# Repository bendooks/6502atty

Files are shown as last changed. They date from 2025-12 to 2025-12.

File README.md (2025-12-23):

# 6502 Atty

A 6502 SBC with an ATMega as a contoller and monitor for the 6502.

This is an initial commit as PCBs are off for manufacture and not been tested. This includes the prototype firmware and the first cut of the firmware code.

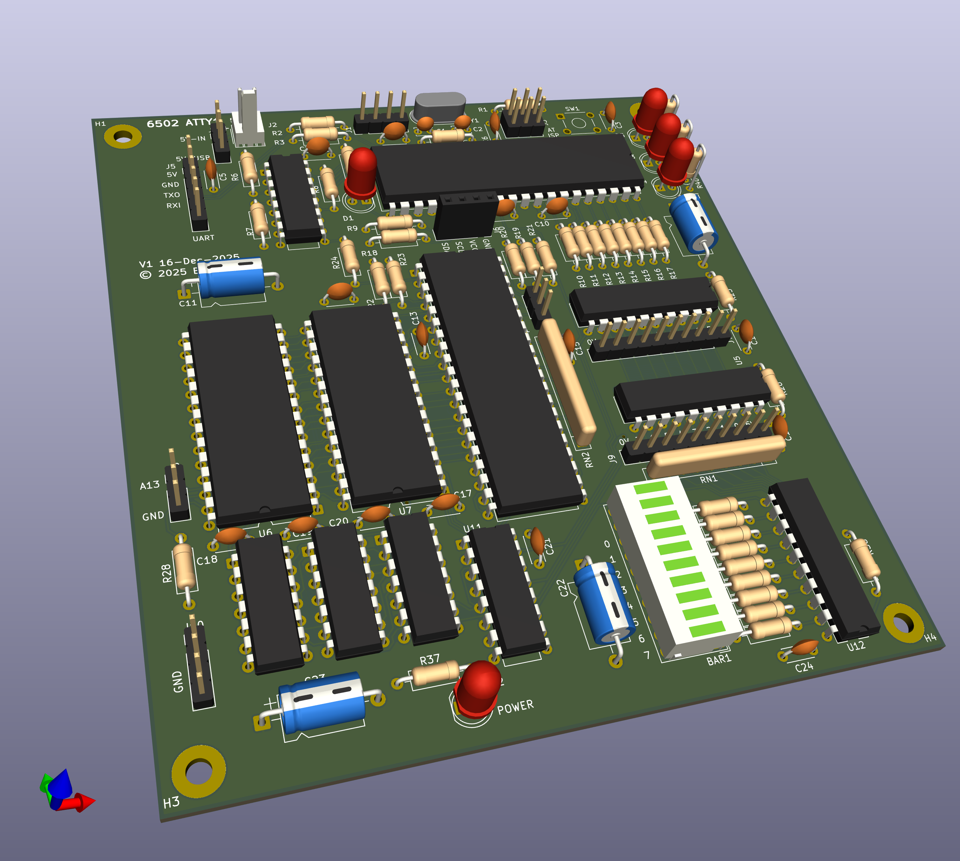
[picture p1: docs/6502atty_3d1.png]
3D PCB view


# Firmware

The firmware is currently in development. To build, you will need at-least avr-gcc and the relevant libraries and is currently only being tested on Linux (Debian). Once built, download to the ATMega using something like avrdude.

## Revision information

The original prototype version was built on a perfboard, and not release.

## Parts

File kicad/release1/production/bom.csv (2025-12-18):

Designator | Footprint | Quantity | Value | LCSC Part #
BAR1 | HDSP-4850 | 1 | HDSP-4850
C1, C2 | C_Disc_D3.4mm_W2.1mm_P2.50mm | 2 | 12pF
C10, C3 | C_Disc_D4.3mm_W1.9mm_P5.00mm | 2 | ~
C11, C22, C23, C8 | CP_Axial_L10.0mm_D6.0mm_P15.00mm_Horizontal | 4 | 100uF/16V
C12, C13, C14, C15, C16, C17, C18, C19, C20, C21, C24, C4, C5, C6, C7, C9 | C_Disc_D4.3mm_W1.9mm_P5.00mm | 16 | 100nF
D1 | LED_D5.0mm | 1 | LED_Small_Filled
D2, D3, D4, D5 | LED_D5.0mm | 4 | RED
J1, J10 | PinHeader_1x04_P2.54mm_Vertical | 2 | Conn_01x04_Pin
J11, J4, J8 | PinHeader_1x03_P2.54mm_Vertical | 3 | Conn_01x03_Pin
J2 | Molex_KK-254_AE-6410-02A_1x02_P2.54mm_Vertical | 1 | Conn_01x02_Pin
J3 | PinHeader_2x03_P2.54mm_Vertical | 1 | Conn_02x03_Odd_Even
J5 | PinHeader_1x06_P2.54mm_Vertical | 1 | Conn_01x06_Pin
J6 | PinSocket_1x04_P2.54mm_Vertical | 1 | Conn_01x04_Pin
J7, J9 | PinHeader_1x10_P2.54mm_Vertical | 2 | Conn_01x10_Pin
R1, R2, R3, R37, R4, R5 | R_Axial_DIN0207_L6.3mm_D2.5mm_P10.16mm_Horizontal | 6 | 1K
R10, R11, R12, R13, R14, R15, R16, R17, R27, R29, R30, R31, R32, R33, R34, R35, R38 | R_Axial_DIN0207_L6.3mm_D2.5mm_P10.16mm_Horizontal | 17 | 330R
R18, R9 | R_Axial_DIN0207_L6.3mm_D2.5mm_P10.16mm_Horizontal | 2 | 4K7
R19, R20, R21, R22, R23, R24, R25, R26, R28, R36, R6, R7, R8 | R_Axial_DIN0207_L6.3mm_D2.5mm_P10.16mm_Horizontal | 13 | R
R39, R40, R41 | R_Axial_DIN0207_L6.3mm_D2.5mm_P2.54mm_Vertical | 3 | 1K
RN1, RN2 | R_Array_SIP9 | 2 | R_Network08
SW1 | SW_TH_Tactile_Omron_B3F-10xx | 1 | SW_Push
U1 | DIP-40_W15.24mm | 1 | ATmega164P-20P
U10 | DIP-14_W7.62mm | 1 | 74LS08
U11 | DIP-16_W7.62mm | 1 | 74LS138
U12, U4 | DIP-20_W7.62mm | 2 | 74LS573
U2 | DIP-16_W7.62mm | 1 | 74LS112
U3 | DIP-40_W15.24mm | 1 | W65C02SxP
U5 | DIP-20_W7.62mm | 1 | 74HC245
U6 | DIP-28_W15.24mm | 1 | 27C128
U7 | DIP-28_W15.24mm | 1 | KM62256CLP
U8, U9 | DIP-14_W7.62mm | 2 | 74LS00
Y1 | Crystal_HC49-4H_Vertical | 1 | 18.341MHz

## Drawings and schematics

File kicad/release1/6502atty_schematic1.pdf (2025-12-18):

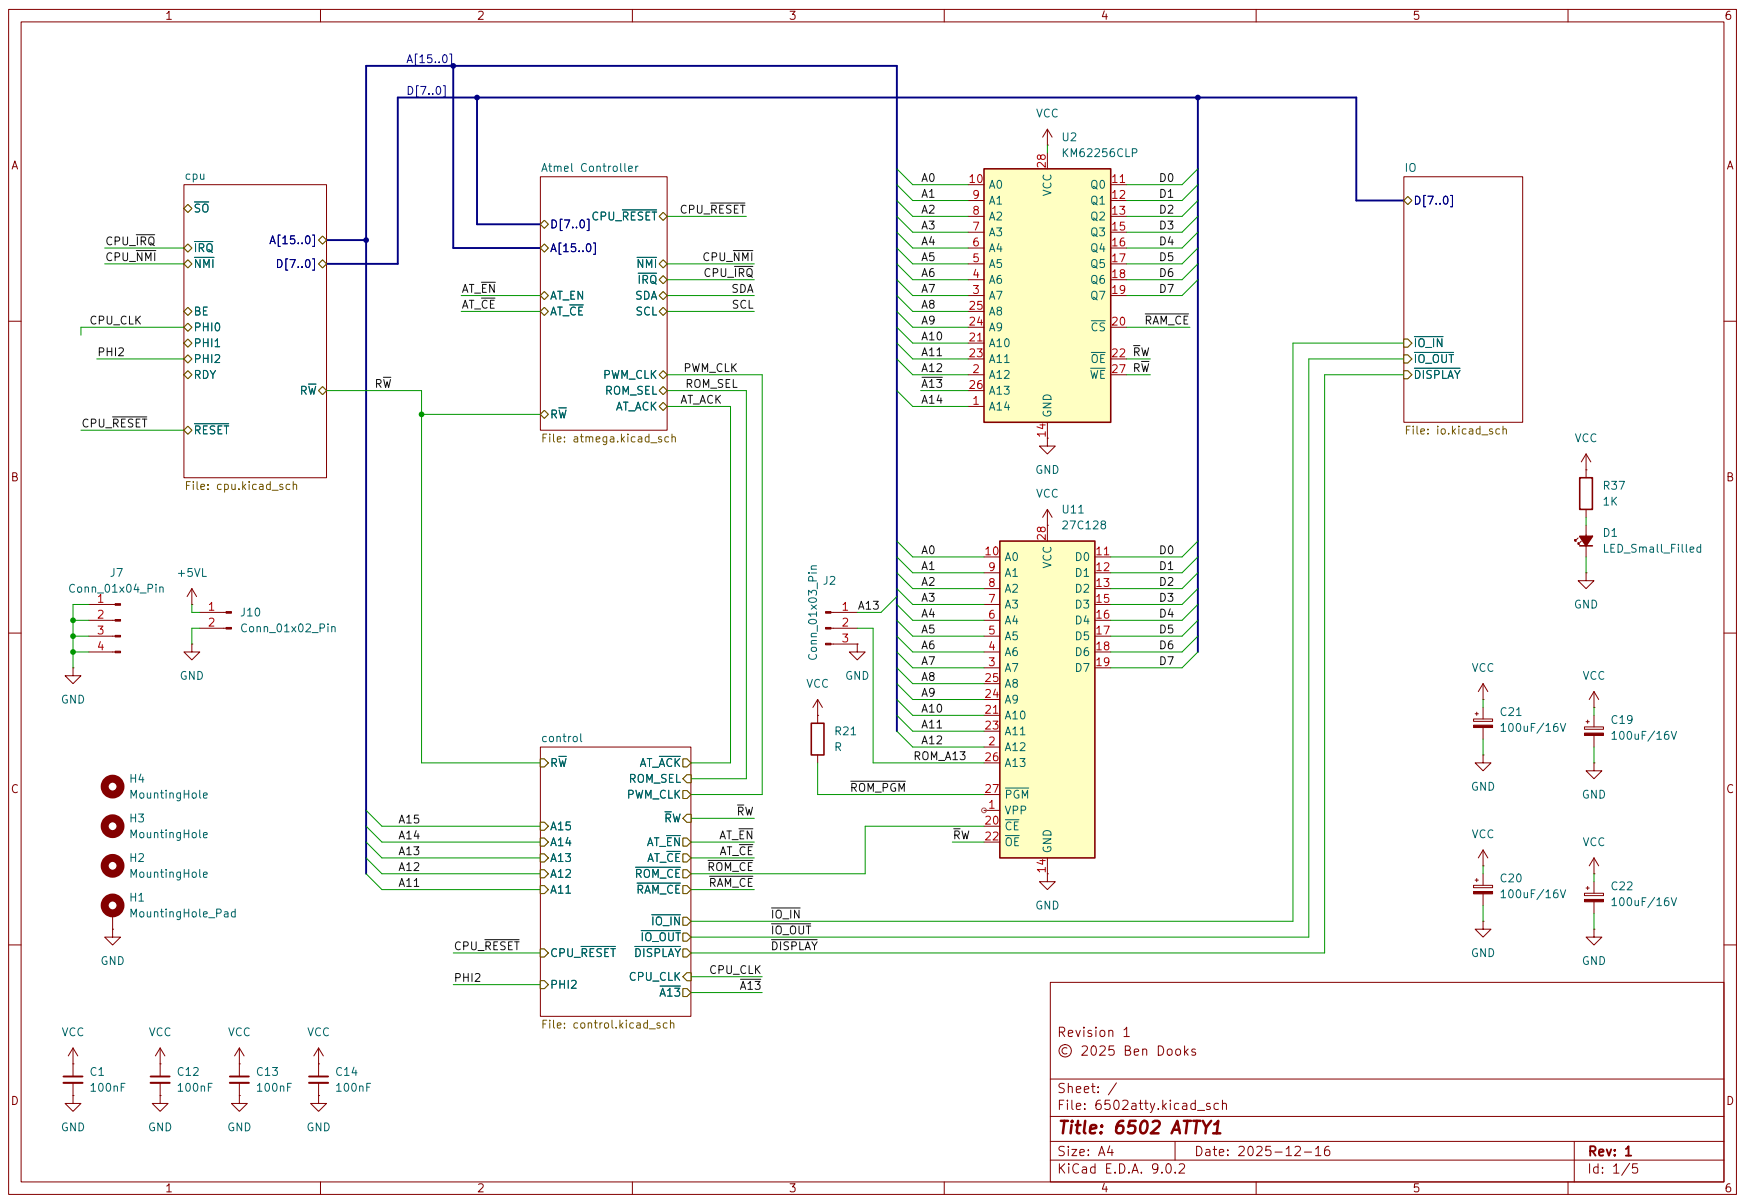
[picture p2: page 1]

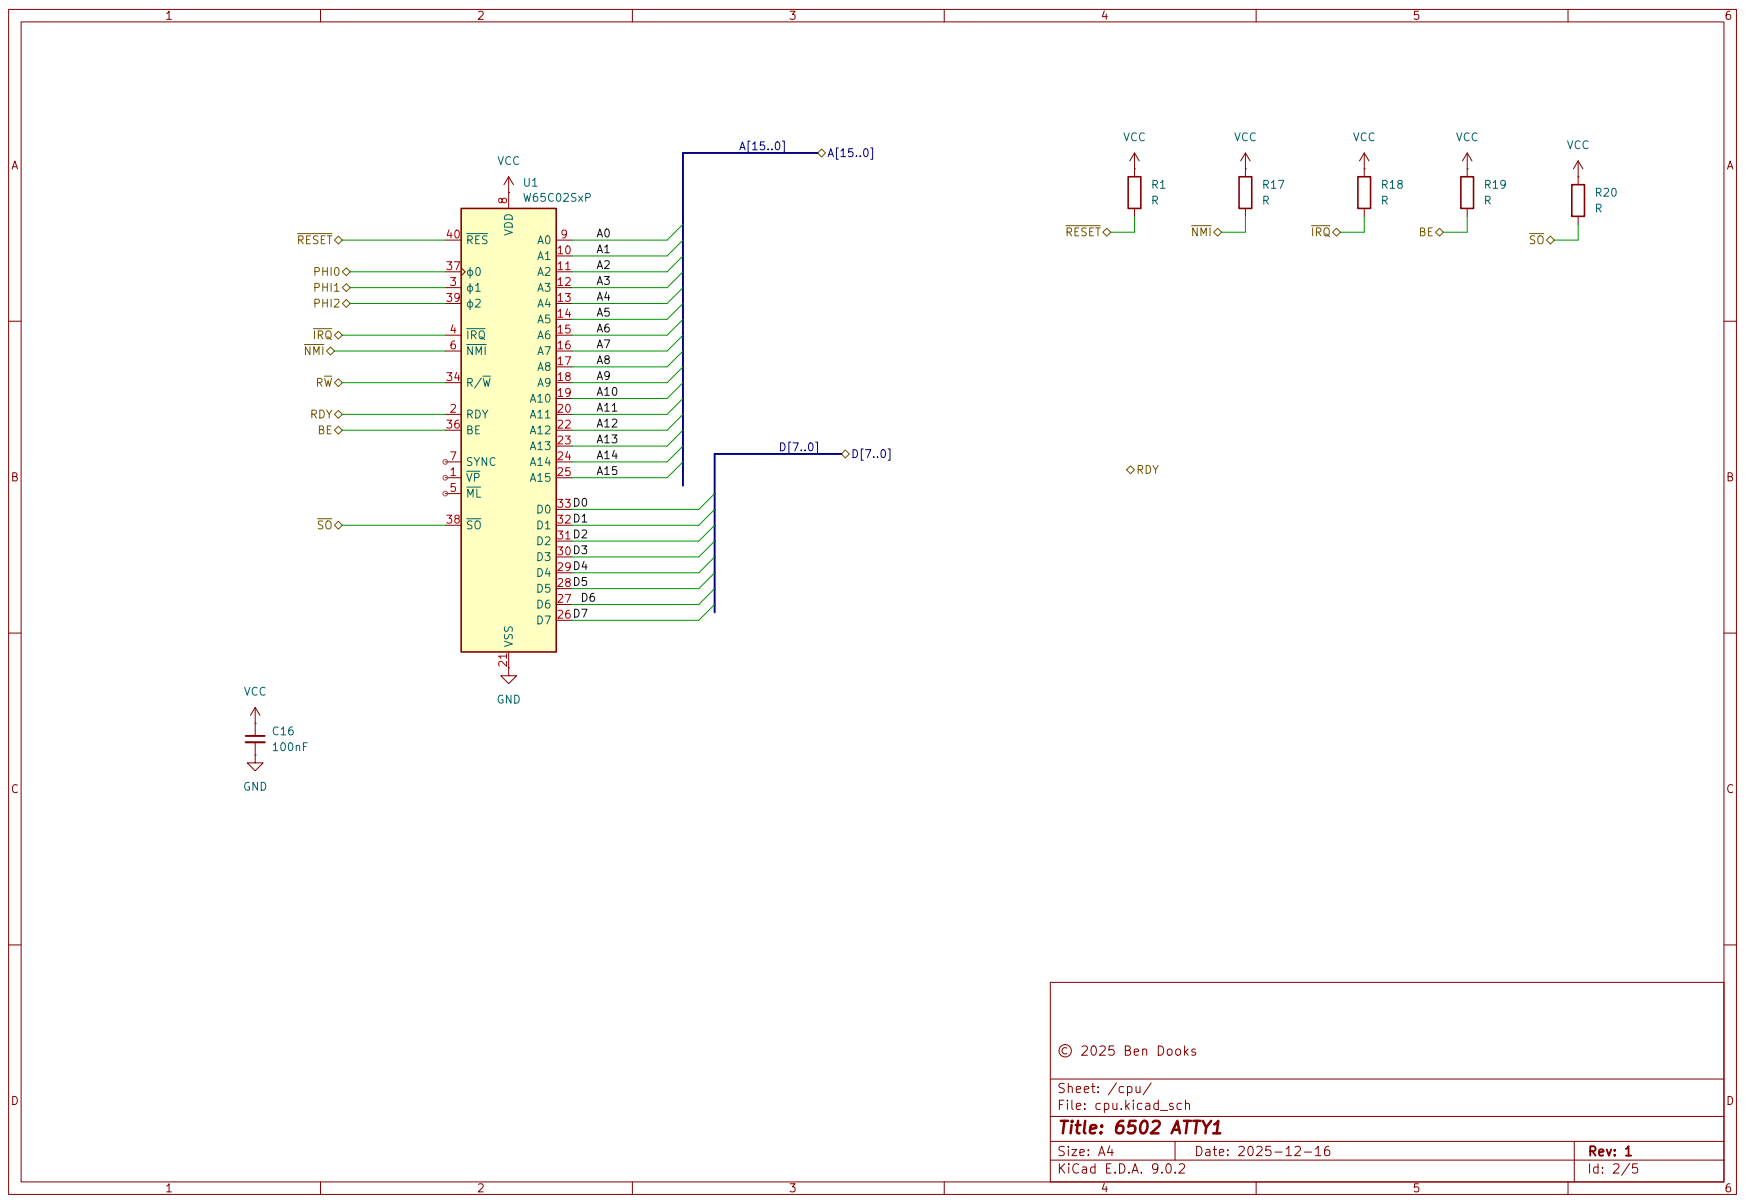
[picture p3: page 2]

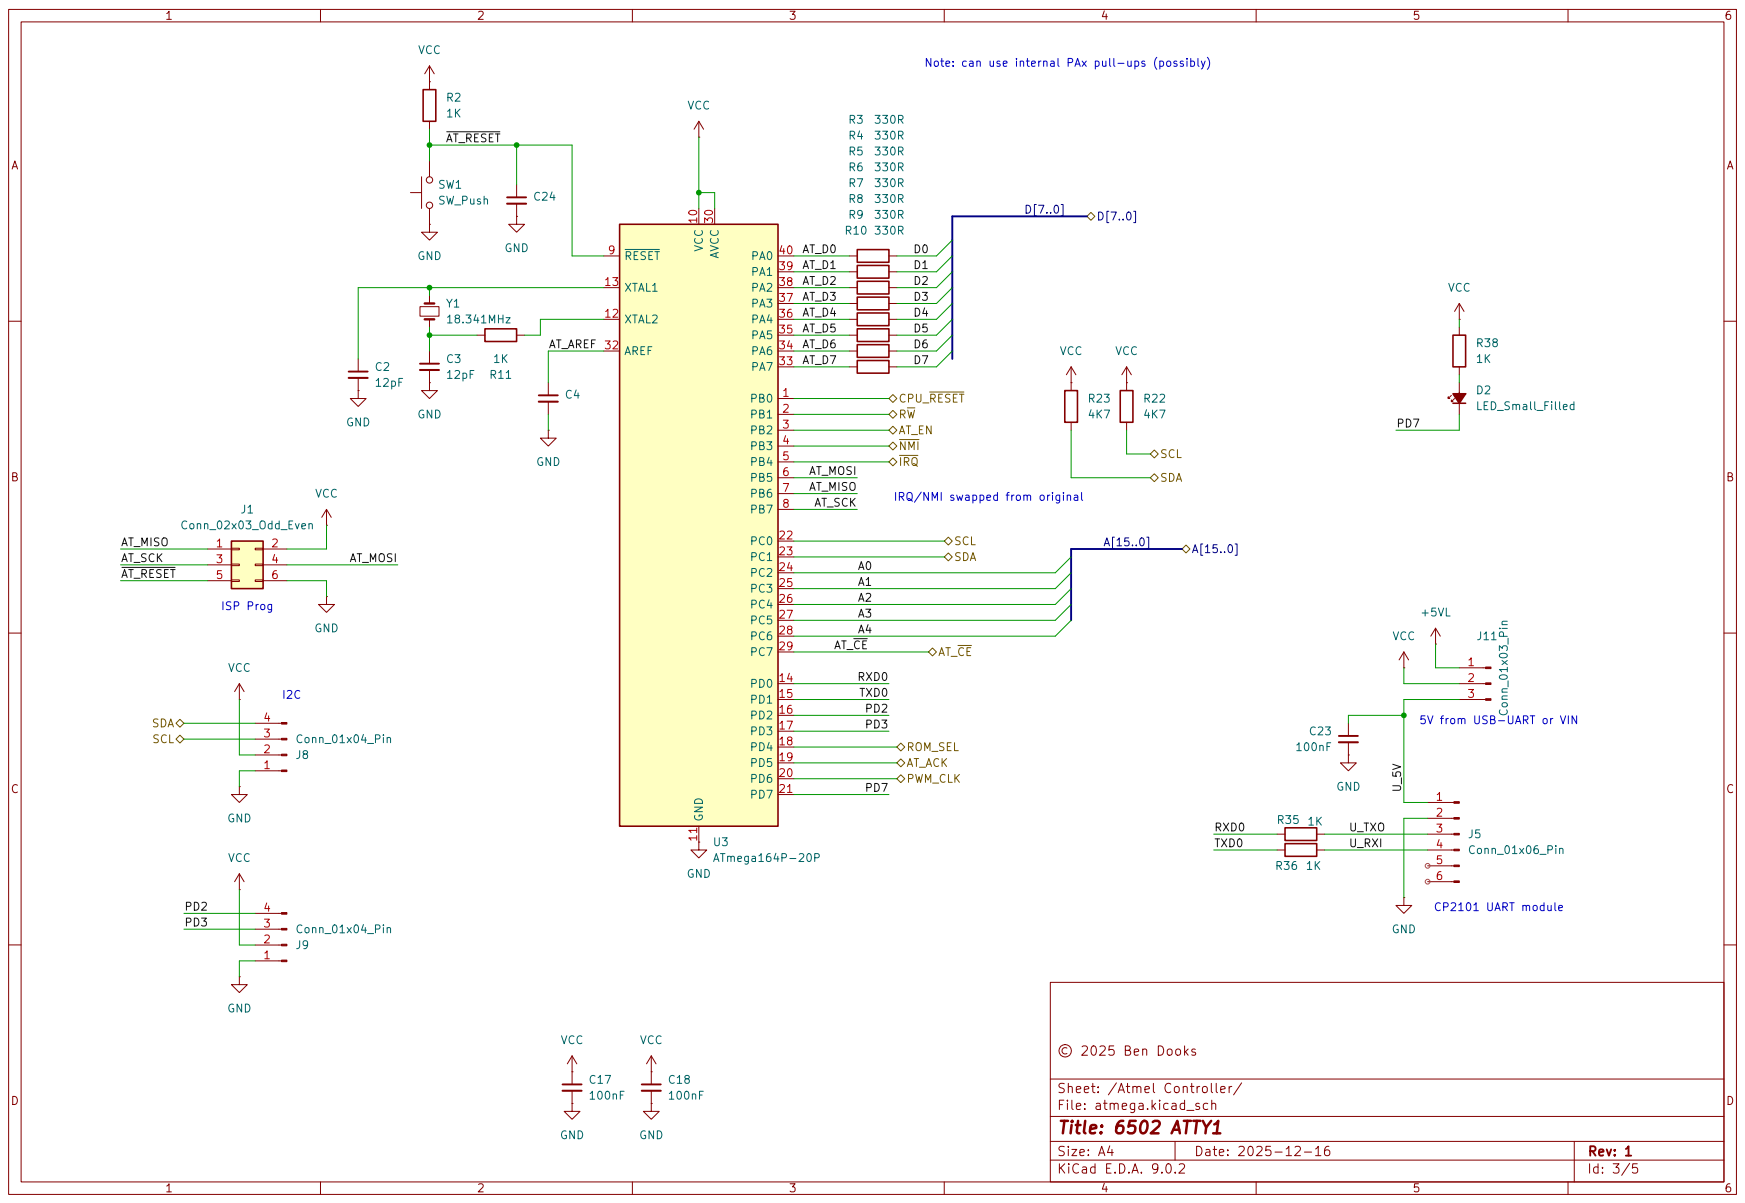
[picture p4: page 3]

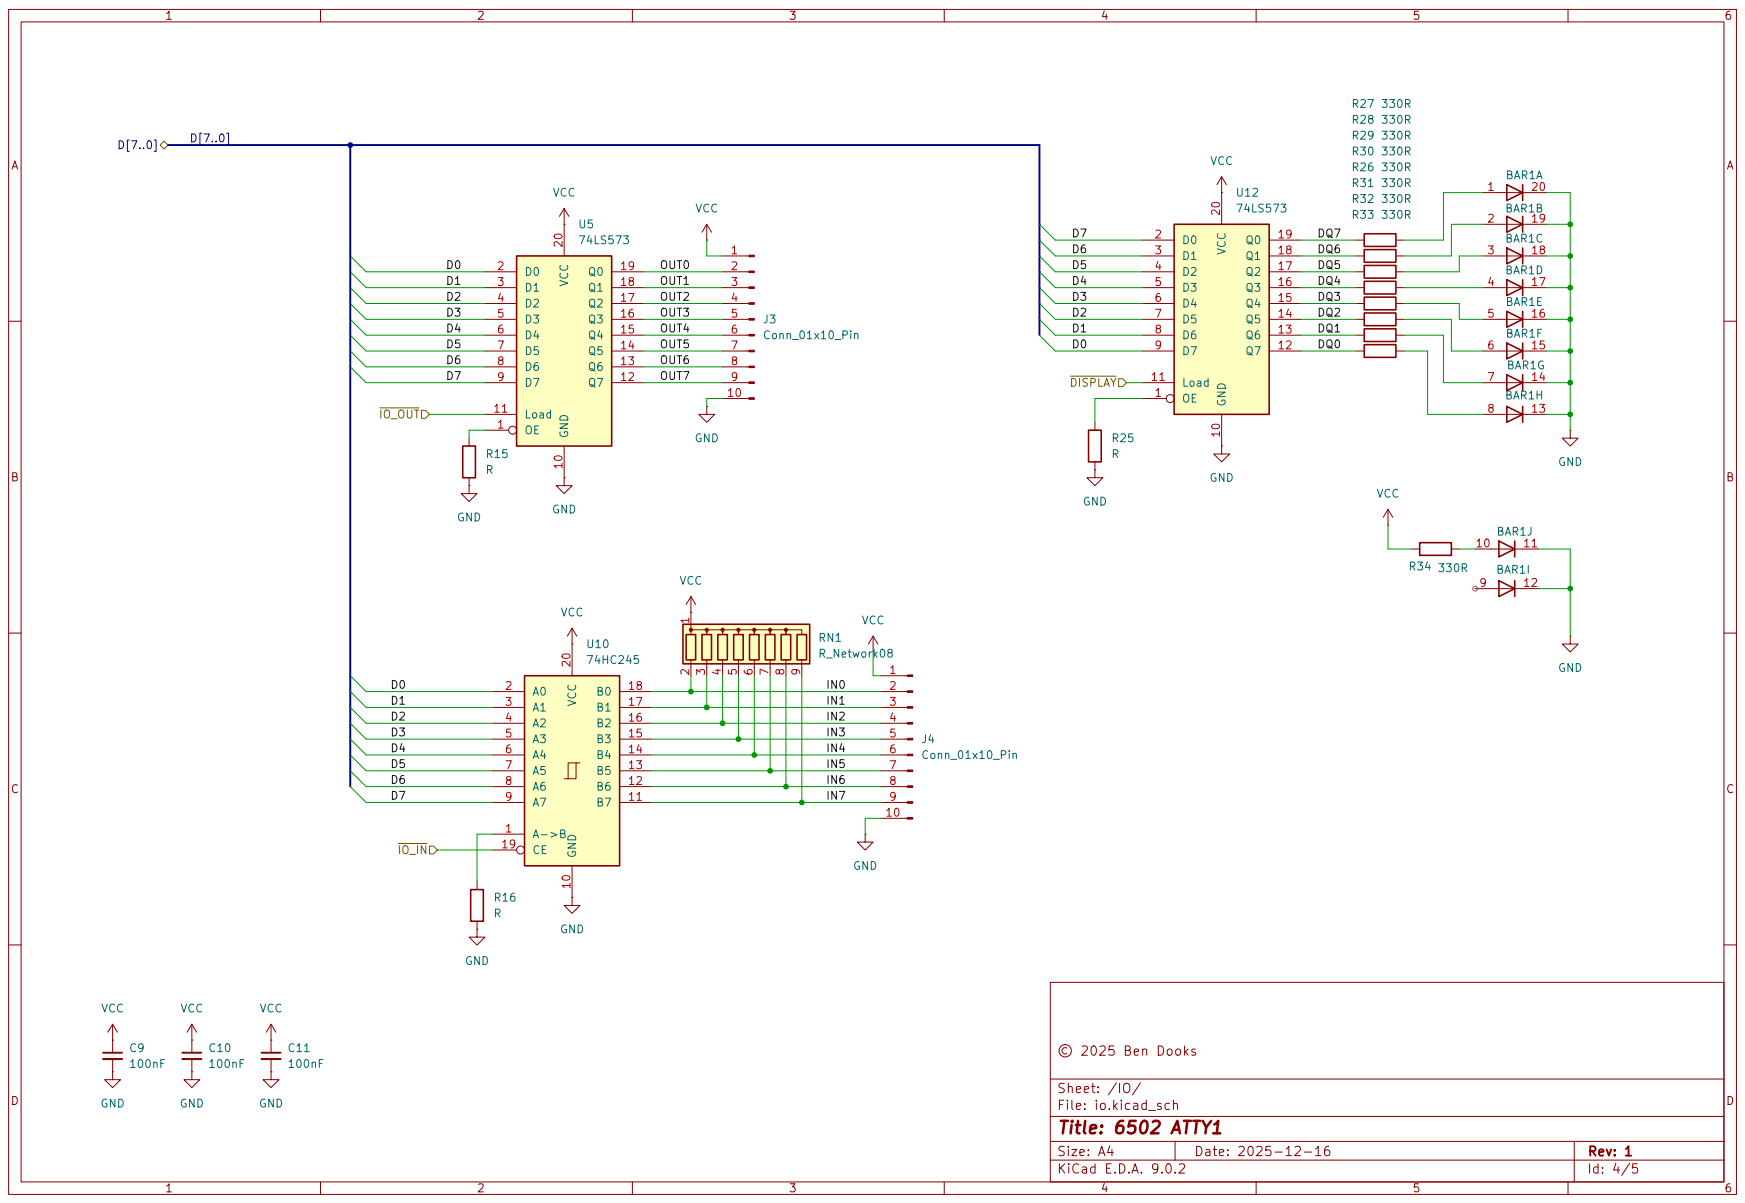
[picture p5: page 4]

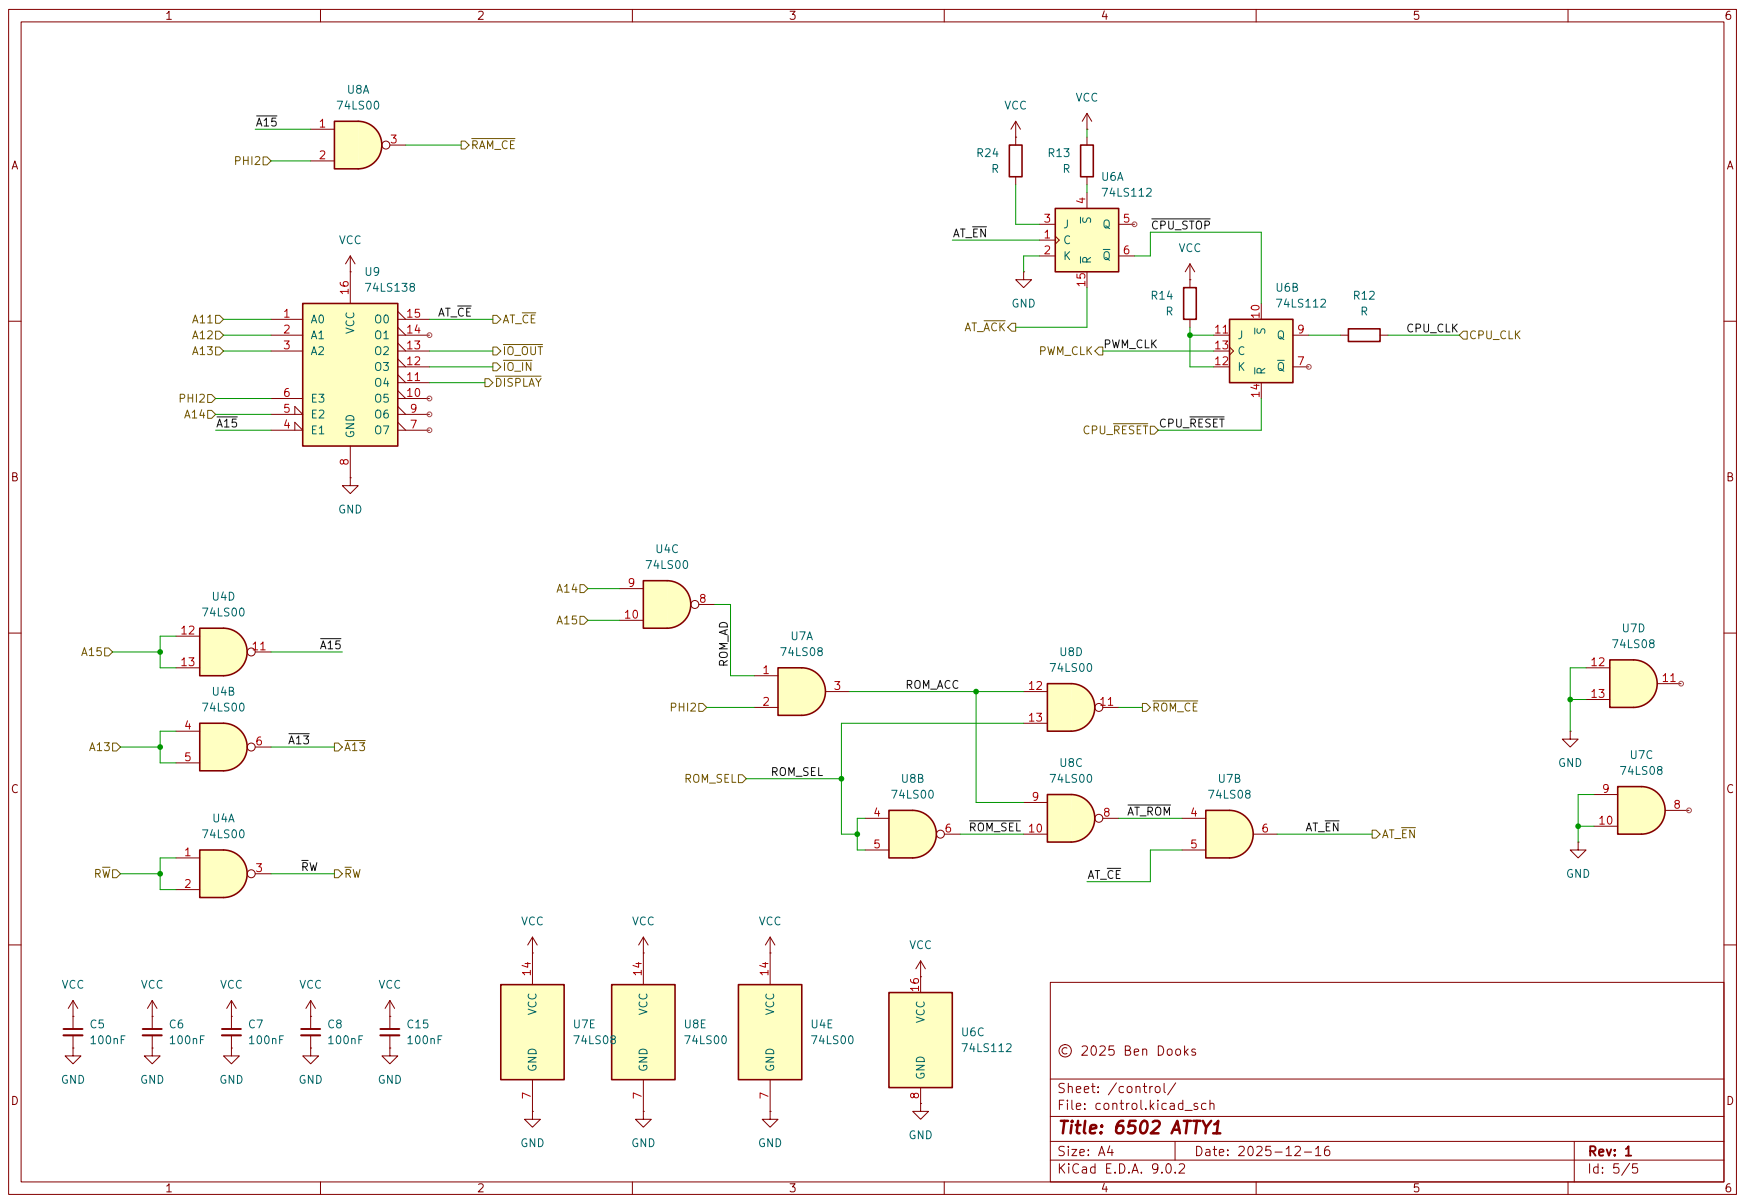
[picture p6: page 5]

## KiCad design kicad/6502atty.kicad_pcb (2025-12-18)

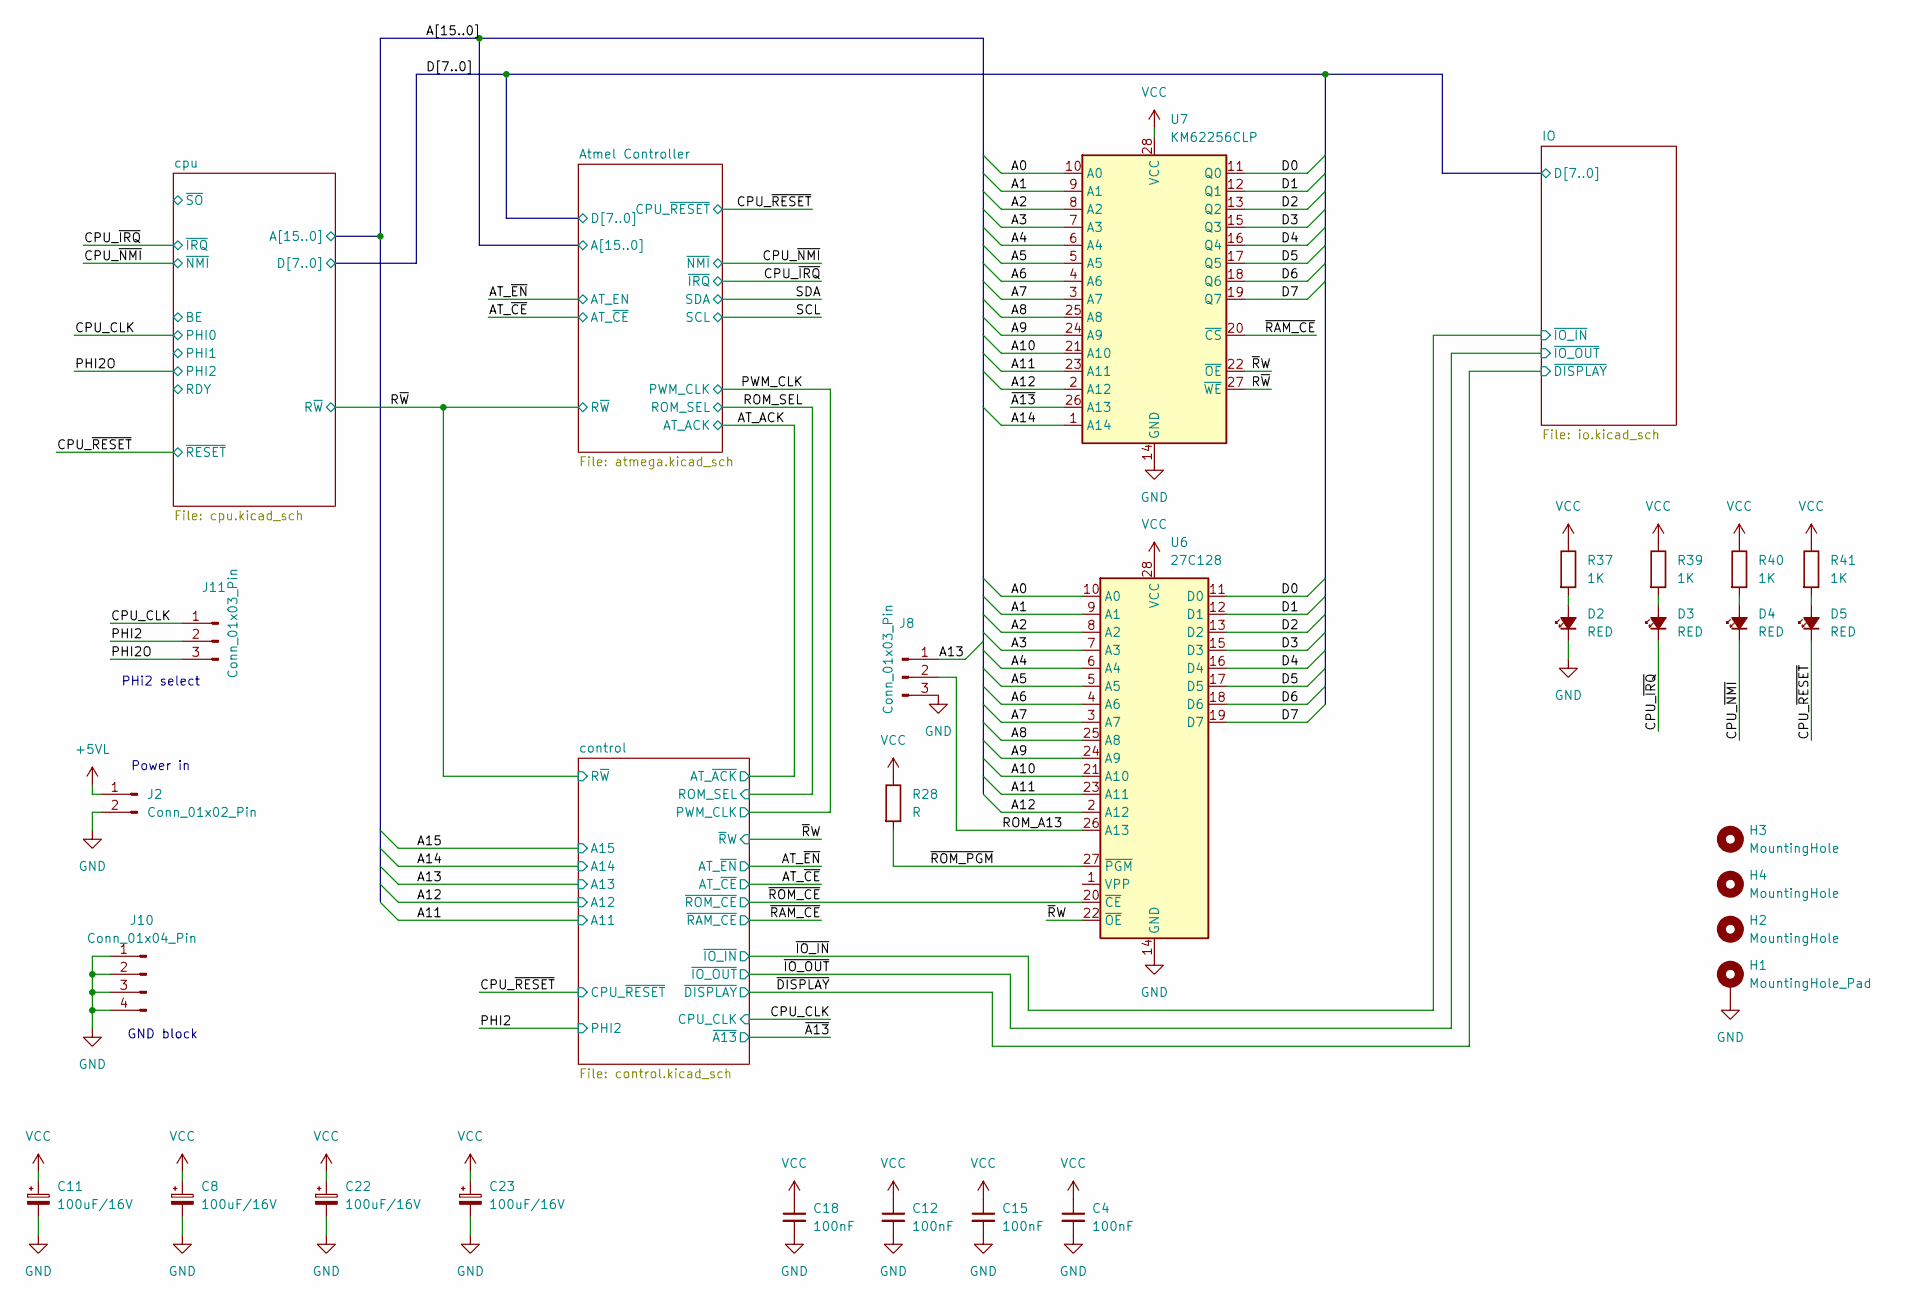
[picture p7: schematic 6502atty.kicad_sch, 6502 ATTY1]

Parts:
C4, C12, C15, C18: 100nF; C_Disc_D4.3mm_W1.9mm_P5.00mm
C8, C11, C22, C23: 100uF/16V; CP_Axial_L10.0mm_D6.0mm_P15.00mm_Horizontal
D2, D3, D4, D5: RED; LED_D5.0mm
H1: MountingHole_Pad; MountingHole_3.2mm_M3_Pad
H2, H3, H4: MountingHole; MountingHole_3.2mm_M3_Pad
J2: Conn_01x02_Pin; Molex_KK-254_AE-6410-02A_1x02_P2.54mm_Vertical
J8, J11: Conn_01x03_Pin; PinHeader_1x03_P2.54mm_Vertical
J10: Conn_01x04_Pin; PinHeader_1x04_P2.54mm_Vertical
R28: R; R_Axial_DIN0207_L6.3mm_D2.5mm_P10.16mm_Horizontal
R37: 1K; R_Axial_DIN0207_L6.3mm_D2.5mm_P10.16mm_Horizontal
R39, R40, R41: 1K; R_Axial_DIN0207_L6.3mm_D2.5mm_P2.54mm_Vertical
U6: 27C128; DIP-28_W15.24mm
U7: KM62256CLP; DIP-28_W15.24mm

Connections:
+5VL: J2.1; also elsewhere on the board
/A0: U6.10 (A0), U7.10 (A0); also elsewhere on the board
/A1: U6.9 (A1), U7.9 (A1); also elsewhere on the board
/A2: U6.8 (A2), U7.8 (A2); also elsewhere on the board
/A3: U6.7 (A3), U7.7 (A3); also elsewhere on the board
/A4: U6.6 (A4), U7.6 (A4); also elsewhere on the board
/A5: U6.5 (A5), U7.5 (A5); also elsewhere on the board
/A6: U6.4 (A6), U7.4 (A6); also elsewhere on the board
/A7: U6.3 (A7), U7.3 (A7); also elsewhere on the board
/A8: U6.25 (A8), U7.25 (A8); also elsewhere on the board
/A9: U6.24 (A9), U7.24 (A9); also elsewhere on the board
/A10: U6.21 (A10), U7.21 (A10); also elsewhere on the board
/A11: U6.23 (A11), U7.23 (A11); also elsewhere on the board
/A12: U6.2 (A12), U7.2 (A12); also elsewhere on the board
/A13: J8.1; also elsewhere on the board
/A14: U7.1 (A14); also elsewhere on the board
/CPU_CLK: J11.1; also elsewhere on the board
/CPU_~IRQ: D3.1 (K); also elsewhere on the board
/CPU_~NMI: D4.1 (K); also elsewhere on the board
/CPU_~RESET: D5.1 (K); also elsewhere on the board
/D0: U6.11 (D0), U7.11 (Q0); also elsewhere on the board
/D1: U6.12 (D1), U7.12 (Q1); also elsewhere on the board
/D2: U6.13 (D2), U7.13 (Q2); also elsewhere on the board
/D3: U6.15 (D3), U7.15 (Q3); also elsewhere on the board
/D4: U6.16 (D4), U7.16 (Q4); also elsewhere on the board
/D5: U6.17 (D5), U7.17 (Q5); also elsewhere on the board
/D6: U6.18 (D6), U7.18 (Q6); also elsewhere on the board
/D7: U6.19 (D7), U7.19 (Q7); also elsewhere on the board
/PHI2: J11.2; also elsewhere on the board
/PHI2O: J11.3; also elsewhere on the board
/ROM_A13: J8.2, U6.26 (A13)
/R~W: U7.27 (~WE); also elsewhere on the board
/~A13: U7.26 (A13); also elsewhere on the board
/~RAM_CE: U7.20 (~CS); also elsewhere on the board
/~ROM_CE: U6.20 (~CE); also elsewhere on the board
/~ROM_PGM: R28.2, U6.27 (~PGM)
/~RW: U6.22 (~OE), U7.22 (~OE); also elsewhere on the board
GND: C4.2, C8.2, C11.2, C12.2, C15.2, C18.2, C22.2, C23.2, D2.1 (K), H1.1, J2.2, J8.3, J10.1, J10.2, J10.3, J10.4, U6.14 (GND), U7.14 (GND); also elsewhere on the board
unnamed: D2.2 (A), R37.2
unnamed: D3.2 (A), R39.2
unnamed: D4.2 (A), R40.2
unnamed: D5.2 (A), R41.2
VCC: C4.1, C8.1, C11.1, C12.1, C15.1, C18.1, C22.1, C23.1, R28.1, R37.1, R39.1, R40.1, R41.1, U6.28 (VCC), U7.28 (VCC); also elsewhere on the board

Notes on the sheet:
Power in
GND block
PHi2 select

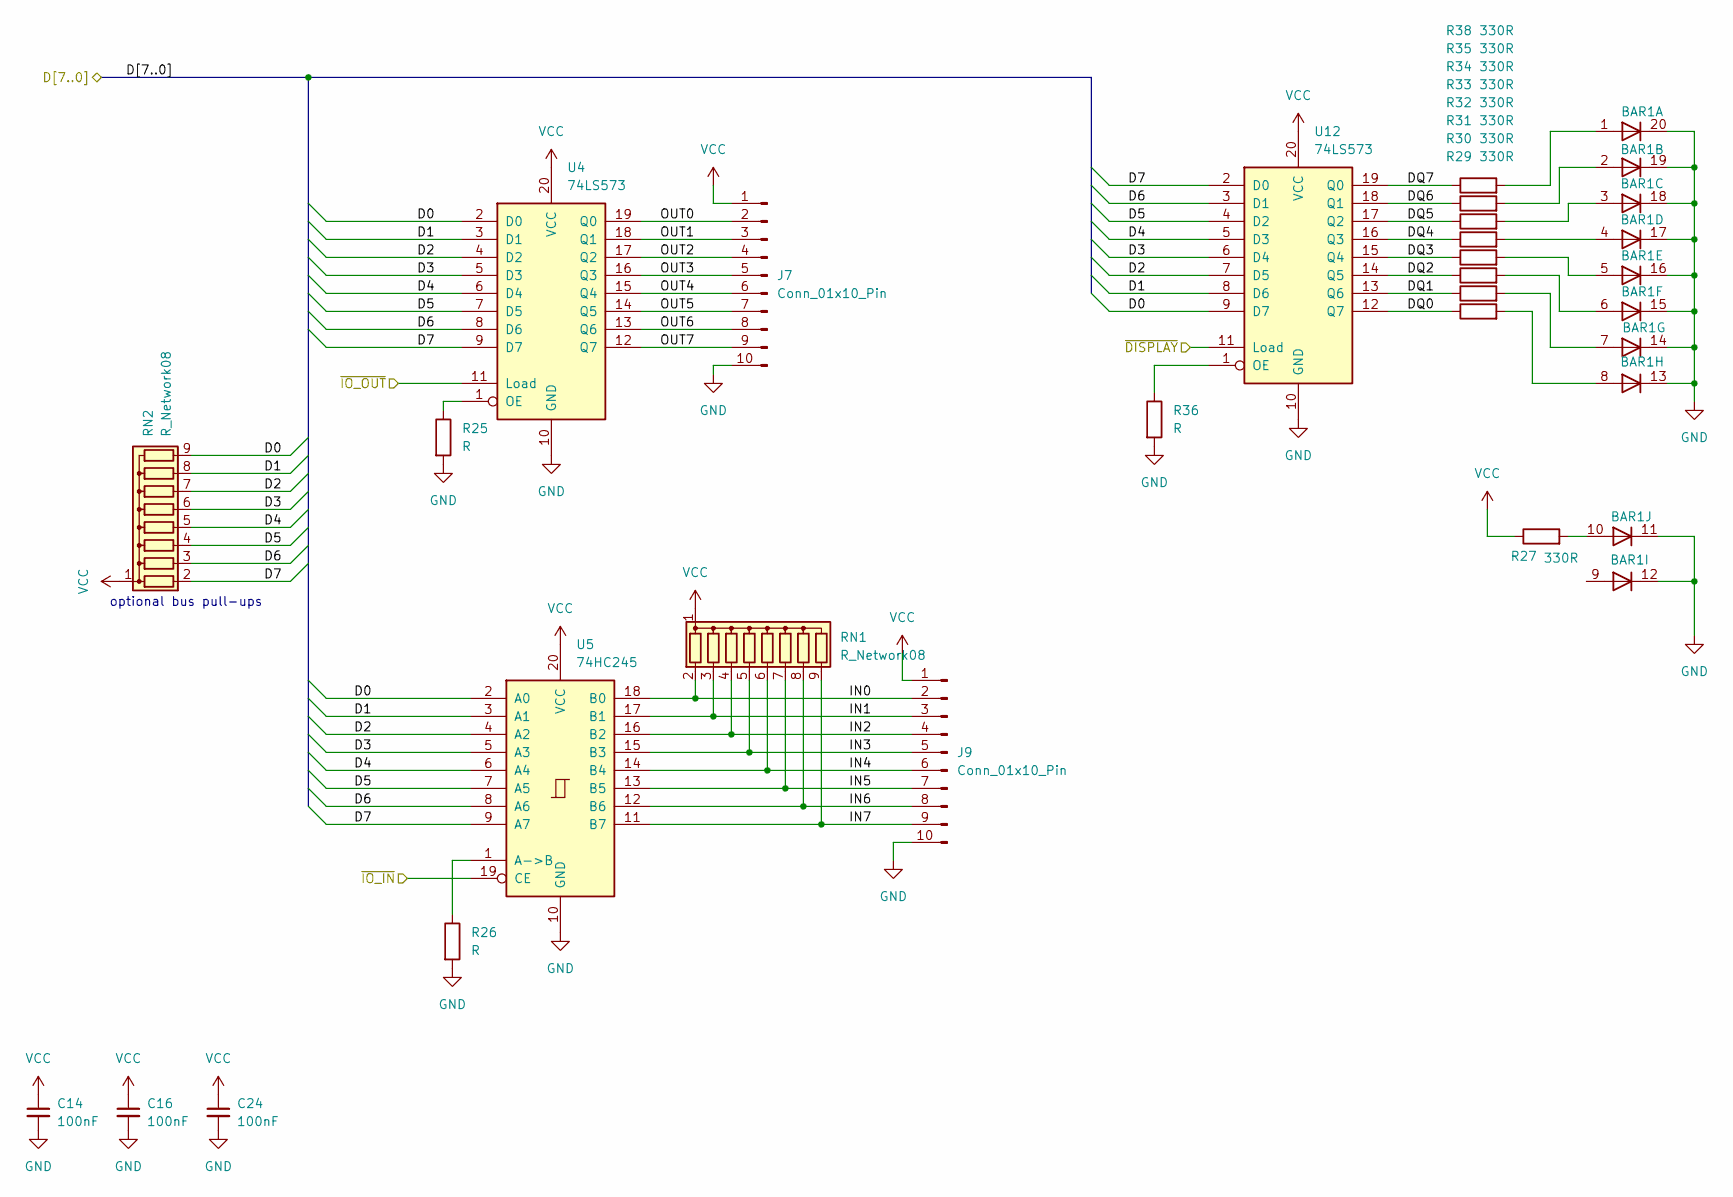
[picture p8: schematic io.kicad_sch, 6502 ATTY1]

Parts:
BAR1: HDSP-4850
C14, C16, C24: 100nF; C_Disc_D4.3mm_W1.9mm_P5.00mm
J7, J9: Conn_01x10_Pin; PinHeader_1x10_P2.54mm_Vertical
R25, R26, R36: R; R_Axial_DIN0207_L6.3mm_D2.5mm_P10.16mm_Horizontal
R27, R29, R30, R31, R32, R33, R34, R35, R38: 330R; R_Axial_DIN0207_L6.3mm_D2.5mm_P10.16mm_Horizontal
RN1, RN2: R_Network08; R_Array_SIP9
U4, U12: 74LS573; DIP-20_W7.62mm
U5: 74HC245; DIP-20_W7.62mm

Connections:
/D0: RN2.9 (R8), U4.2 (D0), U5.2 (A0), U12.9 (D7); also elsewhere on the board
/D1: RN2.8 (R7), U4.3 (D1), U5.3 (A1), U12.8 (D6); also elsewhere on the board
/D2: RN2.7 (R6), U4.4 (D2), U5.4 (A2), U12.7 (D5); also elsewhere on the board
/D3: RN2.6 (R5), U4.5 (D3), U5.5 (A3), U12.6 (D4); also elsewhere on the board
/D4: RN2.5 (R4), U4.6 (D4), U5.6 (A4), U12.5 (D3); also elsewhere on the board
/D5: RN2.4 (R3), U4.7 (D5), U5.7 (A5), U12.4 (D2); also elsewhere on the board
/D6: RN2.3 (R2), U4.8 (D6), U5.8 (A6), U12.3 (D1); also elsewhere on the board
/D7: RN2.2 (R1), U4.9 (D7), U5.9 (A7), U12.2 (D0); also elsewhere on the board
/IO/DQ0: R29.1, U12.12 (Q7)
/IO/DQ1: R30.1, U12.13 (Q6)
/IO/DQ2: R31.1, U12.14 (Q5)
/IO/DQ3: R32.1, U12.15 (Q4)
/IO/DQ4: R33.1, U12.16 (Q3)
/IO/DQ5: R34.1, U12.17 (Q2)
/IO/DQ6: R35.1, U12.18 (Q1)
/IO/DQ7: R38.1, U12.19 (Q0)
/IO/IN0: J9.2, RN1.2 (R1), U5.18 (B0)
/IO/IN1: J9.3, RN1.3 (R2), U5.17 (B1)
/IO/IN2: J9.4, RN1.4 (R3), U5.16 (B2)
/IO/IN3: J9.5, RN1.5 (R4), U5.15 (B3)
/IO/IN4: J9.6, RN1.6 (R5), U5.14 (B4)
/IO/IN5: J9.7, RN1.7 (R6), U5.13 (B5)
/IO/IN6: J9.8, RN1.8 (R7), U5.12 (B6)
/IO/IN7: J9.9, RN1.9 (R8), U5.11 (B7)
/IO/OUT0: J7.2, U4.19 (Q0)
/IO/OUT1: J7.3, U4.18 (Q1)
/IO/OUT2: J7.4, U4.17 (Q2)
/IO/OUT3: J7.5, U4.16 (Q3)
/IO/OUT4: J7.6, U4.15 (Q4)
/IO/OUT5: J7.7, U4.14 (Q5)
/IO/OUT6: J7.8, U4.13 (Q6)
/IO/OUT7: J7.9, U4.12 (Q7)
/~DISPLAY: U12.11 (Load); also elsewhere on the board
/~IO_IN: U5.19 (CE); also elsewhere on the board
/~IO_OUT: U4.11 (Load); also elsewhere on the board
GND: BAR1.11 (K), BAR1.12 (K), BAR1.13 (K), BAR1.14 (K), BAR1.15 (K), BAR1.16 (K), BAR1.17 (K), BAR1.18 (K), BAR1.19 (K), BAR1.20 (K), C14.2, C16.2, C24.2, J7.10, J9.10, R25.2, R26.2, R36.2, U4.10 (GND), U5.10 (GND), U12.10 (GND); also elsewhere on the board
unnamed: BAR1.1 (A), R38.2
unnamed: BAR1.2 (A), R35.2
unnamed: BAR1.3 (A), R34.2
unnamed: BAR1.4 (A), R33.2
unnamed: BAR1.5 (A), R32.2
unnamed: BAR1.6 (A), R31.2
unnamed: BAR1.7 (A), R30.2
unnamed: BAR1.8 (A), R29.2
unnamed: BAR1.10 (A), R27.2
unnamed: R25.1, U4.1 (OE)
unnamed: R26.1, U5.1 (A->B)
unnamed: R36.1, U12.1 (OE)
VCC: C14.1, C16.1, C24.1, J7.1, J9.1, R27.1, RN1.1 (common), RN2.1 (common), U4.20 (VCC), U5.20 (VCC), U12.20 (VCC); also elsewhere on the board

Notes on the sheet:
optional bus pull-ups

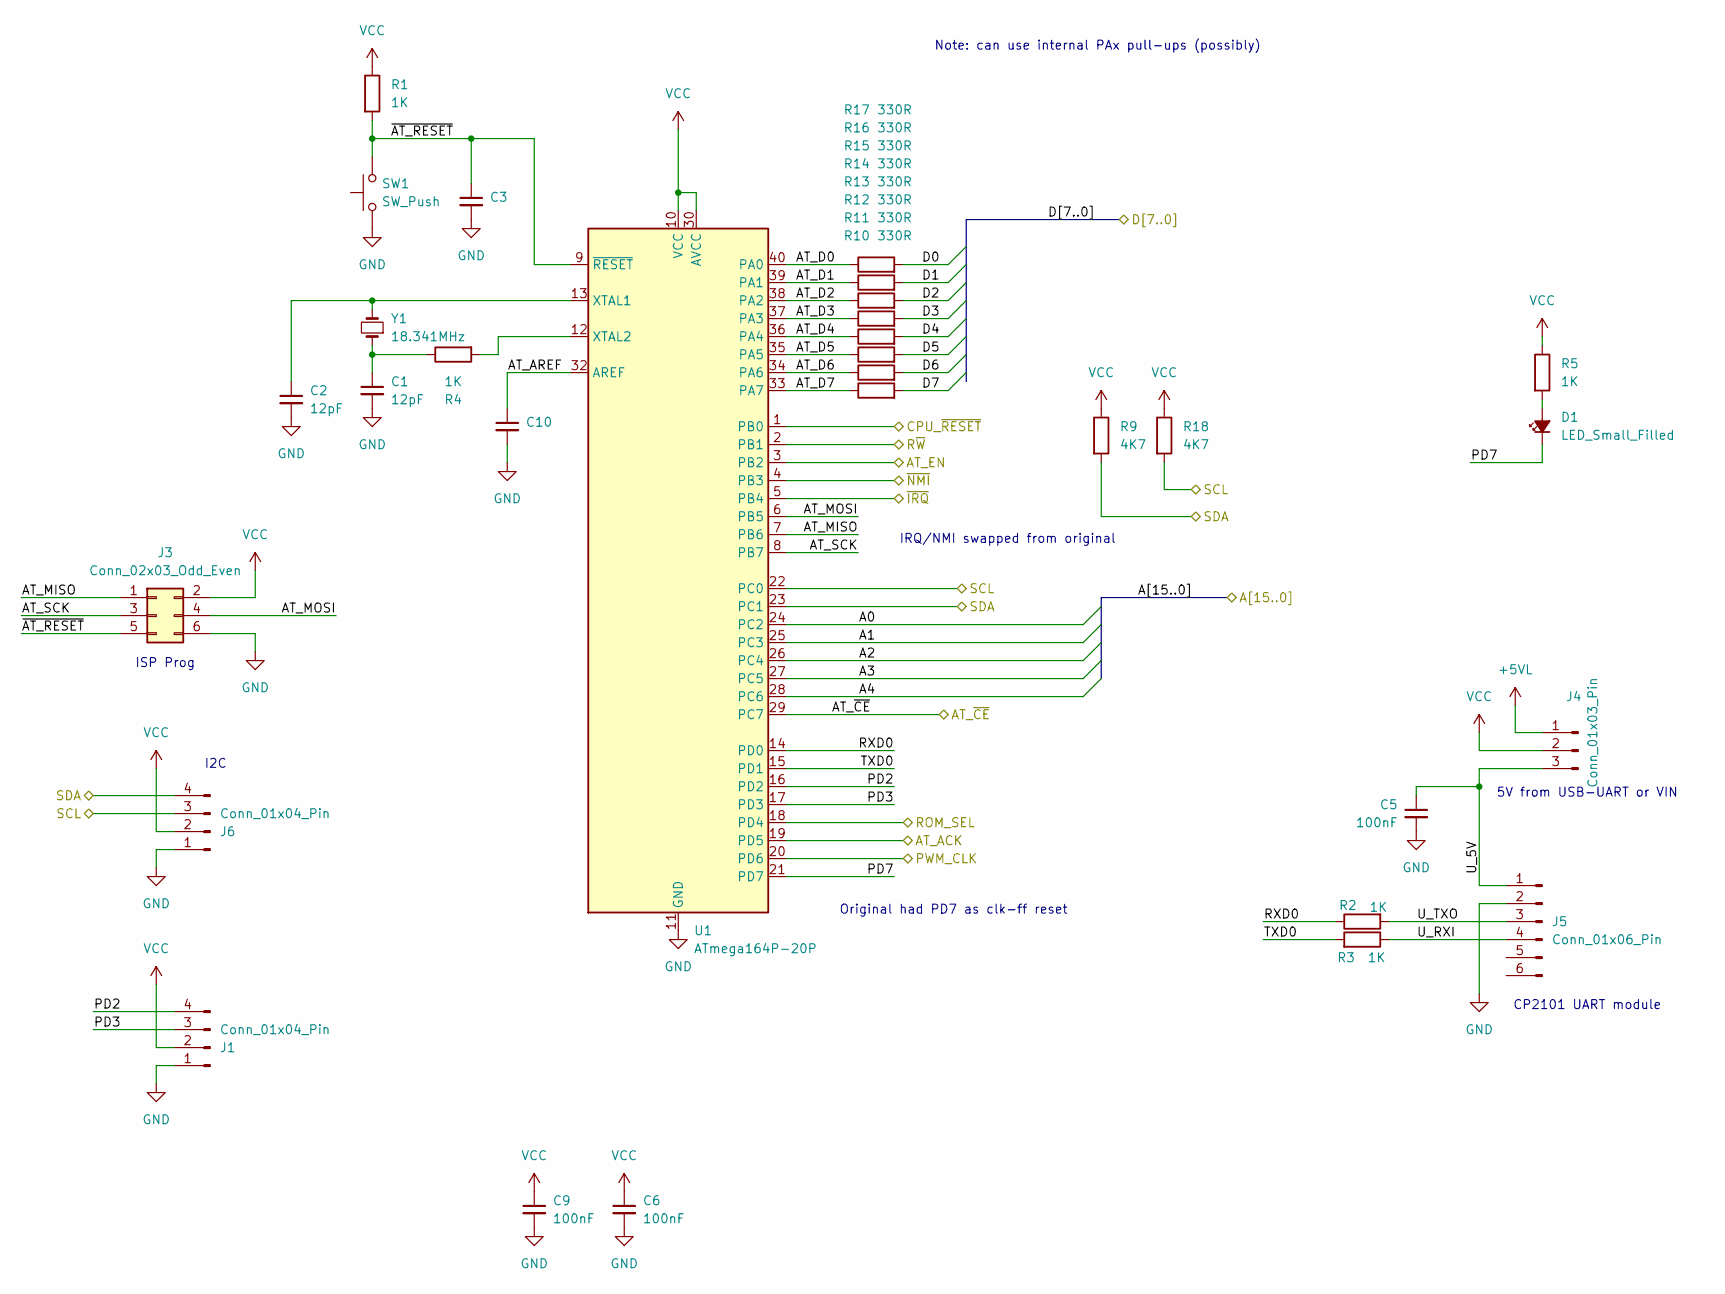
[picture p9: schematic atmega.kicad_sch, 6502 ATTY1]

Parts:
C1, C2: 12pF; C_Disc_D3.4mm_W2.1mm_P2.50mm
C3, C10: C_Disc_D4.3mm_W1.9mm_P5.00mm
C5, C6, C9: 100nF; C_Disc_D4.3mm_W1.9mm_P5.00mm
D1: LED_Small_Filled; LED_D5.0mm
J1: Conn_01x04_Pin; PinHeader_1x04_P2.54mm_Vertical
J3: Conn_02x03_Odd_Even; PinHeader_2x03_P2.54mm_Vertical
J4: Conn_01x03_Pin; PinHeader_1x03_P2.54mm_Vertical
J5: Conn_01x06_Pin; PinHeader_1x06_P2.54mm_Vertical
J6: Conn_01x04_Pin; PinSocket_1x04_P2.54mm_Vertical
R1, R2, R3, R4, R5: 1K; R_Axial_DIN0207_L6.3mm_D2.5mm_P10.16mm_Horizontal
R9, R18: 4K7; R_Axial_DIN0207_L6.3mm_D2.5mm_P10.16mm_Horizontal
R10, R11, R12, R13, R14, R15, R16, R17: 330R; R_Axial_DIN0207_L6.3mm_D2.5mm_P10.16mm_Horizontal
SW1: SW_Push; SW_TH_Tactile_Omron_B3F-10xx
U1: ATmega164P-20P; DIP-40_W15.24mm
Y1: 18.341MHz; Crystal_HC49-4H_Vertical

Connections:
+5VL: J4.1; also elsewhere on the board
/A0: U1.24 (PC2); also elsewhere on the board
/A1: U1.25 (PC3); also elsewhere on the board
/A2: U1.26 (PC4); also elsewhere on the board
/A3: U1.27 (PC5); also elsewhere on the board
/A4: U1.28 (PC6); also elsewhere on the board
/AT_ACK: U1.19 (PD5); also elsewhere on the board
/AT_~CE: U1.29 (PC7); also elsewhere on the board
/AT_~EN: U1.3 (PB2); also elsewhere on the board
/Atmel Controller/AT_AREF: C10.1, U1.32 (AREF)
/Atmel Controller/AT_D0: R17.1, U1.40 (PA0)
/Atmel Controller/AT_D1: R16.1, U1.39 (PA1)
/Atmel Controller/AT_D2: R15.1, U1.38 (PA2)
/Atmel Controller/AT_D3: R14.1, U1.37 (PA3)
/Atmel Controller/AT_D4: R13.1, U1.36 (PA4)
/Atmel Controller/AT_D5: R12.1, U1.35 (PA5)
/Atmel Controller/AT_D6: R11.1, U1.34 (PA6)
/Atmel Controller/AT_D7: R10.1, U1.33 (PA7)
/Atmel Controller/AT_MISO: J3.1, U1.7 (PB6)
/Atmel Controller/AT_MOSI: J3.4, U1.6 (PB5)
/Atmel Controller/AT_SCK: J3.3, U1.8 (PB7)
/Atmel Controller/PD2: J1.4, U1.16 (PD2)
/Atmel Controller/PD3: J1.3, U1.17 (PD3)
/Atmel Controller/PD7: D1.1 (K), U1.21 (PD7)
/Atmel Controller/RXD0: R2.1, U1.14 (PD0)
/Atmel Controller/TXD0: R3.2, U1.15 (PD1)
/Atmel Controller/U_5V: C5.1, J4.3, J5.1
/Atmel Controller/U_RXI: J5.4, R3.1
/Atmel Controller/U_TXO: J5.3, R2.2
/Atmel Controller/~AT_RESET: C3.1, J3.5, R1.2, SW1.2, U1.9 (~RESET)
/CPU_~IRQ: U1.5 (PB4); also elsewhere on the board
/CPU_~NMI: U1.4 (PB3); also elsewhere on the board
/CPU_~RESET: U1.1 (PB0); also elsewhere on the board
/D0: R17.2; also elsewhere on the board
/D1: R16.2; also elsewhere on the board
/D2: R15.2; also elsewhere on the board
/D3: R14.2; also elsewhere on the board
/D4: R13.2; also elsewhere on the board
/D5: R12.2; also elsewhere on the board
/D6: R11.2; also elsewhere on the board
/D7: R10.2; also elsewhere on the board
/PWM_CLK: U1.20 (PD6); also elsewhere on the board
/ROM_SEL: U1.18 (PD4); also elsewhere on the board
/R~W: U1.2 (PB1); also elsewhere on the board
/SCL: J6.3, R18.2, U1.22 (PC0)
/SDA: J6.4, R9.2, U1.23 (PC1)
GND: C1.2, C2.2, C3.2, C5.2, C6.2, C9.2, C10.2, J1.1, J3.6, J5.2, J6.1, SW1.1, U1.11 (GND), U1.31 (GND); also elsewhere on the board
unnamed: C1.1, R4.1, Y1.1
unnamed: D1.2 (A), R5.2
unnamed: C2.1, U1.13 (XTAL1), Y1.2
unnamed: R4.2, U1.12 (XTAL2)
VCC: C6.1, C9.1, J1.2, J3.2, J4.2, J6.2, R1.1, R5.1, R9.1, R18.1, U1.10 (VCC), U1.30 (AVCC); also elsewhere on the board

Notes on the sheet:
ISP Prog
I2C
5V from USB-UART or VIN
Original had PD7 as clk-ff reset
IRQ/NMI swapped from original
Note: can use internal PAx pull-ups (possibly)
CP2101 UART module

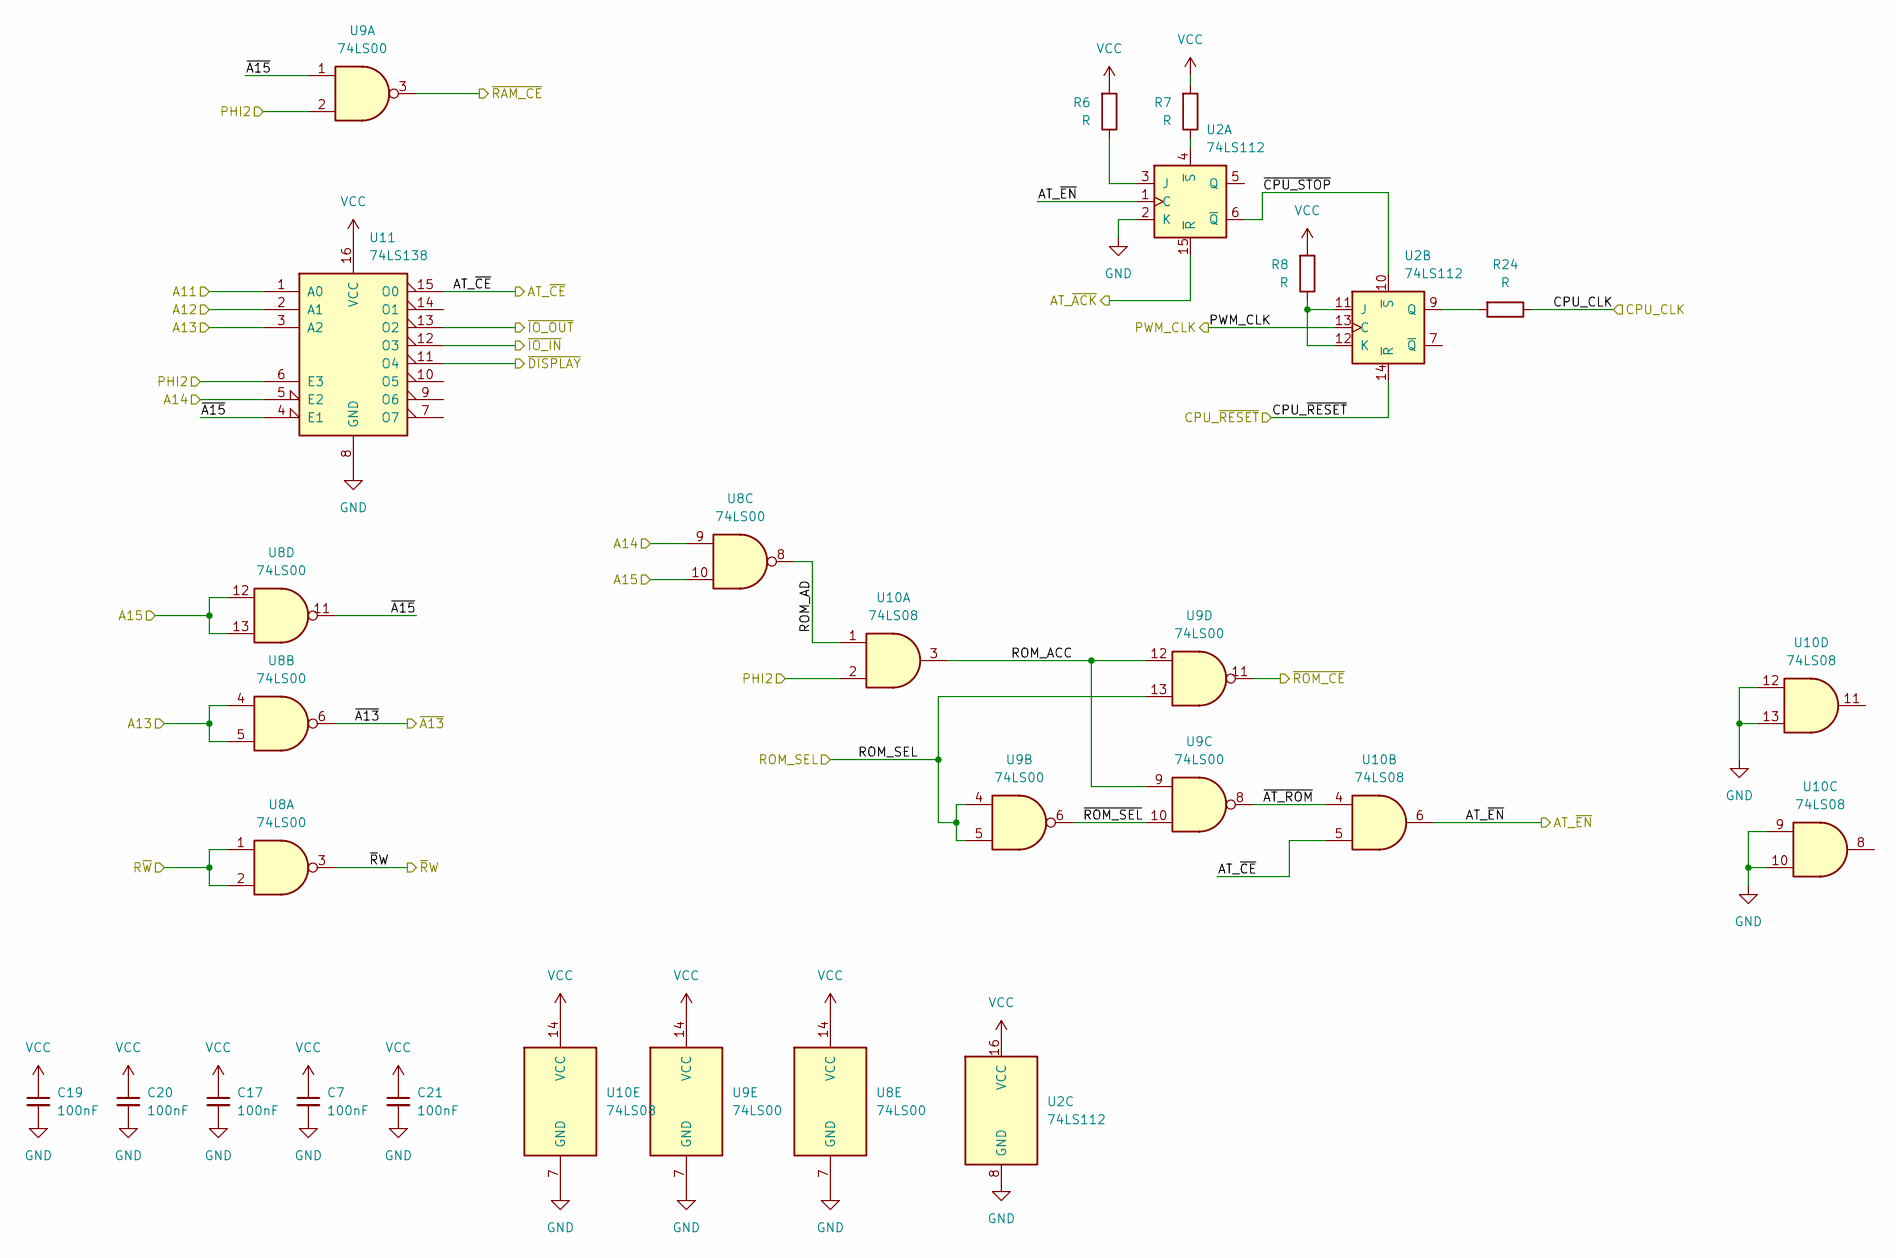
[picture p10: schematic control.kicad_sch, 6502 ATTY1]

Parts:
C7, C17, C19, C20, C21: 100nF; C_Disc_D4.3mm_W1.9mm_P5.00mm
R6, R7, R8, R24: R; R_Axial_DIN0207_L6.3mm_D2.5mm_P10.16mm_Horizontal
U2: 74LS112; DIP-16_W7.62mm
U8, U9: 74LS00; DIP-14_W7.62mm
U10: 74LS08; DIP-14_W7.62mm
U11: 74LS138; DIP-16_W7.62mm

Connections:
/A11: U11.1 (A0); also elsewhere on the board
/A12: U11.2 (A1); also elsewhere on the board
/A13: U8.4, U8.5, U11.3 (A2); also elsewhere on the board
/A14: U8.9, U11.5 (E2); also elsewhere on the board
/A15: U8.10, U8.12, U8.13; also elsewhere on the board
/AT_ACK: U2.15 (~R); also elsewhere on the board
/AT_~CE: U10.5, U11.15 (O0); also elsewhere on the board
/AT_~EN: U2.1 (C), U10.6; also elsewhere on the board
/CPU_CLK: R24.1; also elsewhere on the board
/CPU_~RESET: U2.14 (~R); also elsewhere on the board
/PHI2: U9.2, U10.2, U11.6 (E3); also elsewhere on the board
/PWM_CLK: U2.13 (C); also elsewhere on the board
/ROM_SEL: U9.4, U9.5, U9.13; also elsewhere on the board
/R~W: U8.1, U8.2; also elsewhere on the board
/control/ROM_ACC: U9.9, U9.12, U10.3
/control/ROM_AD: U8.8, U10.1
/control/~A15: U8.11, U9.1, U11.4 (E1)
/control/~AT_ROM: U9.8, U10.4
/control/~CPU_STOP: U2.6 (~Q), U2.10 (~S)
/control/~ROM_SEL: U9.6, U9.10
/~A13: U8.6; also elsewhere on the board
/~DISPLAY: U11.11 (O4); also elsewhere on the board
/~IO_IN: U11.12 (O3); also elsewhere on the board
/~IO_OUT: U11.13 (O2); also elsewhere on the board
/~RAM_CE: U9.3; also elsewhere on the board
/~ROM_CE: U9.11; also elsewhere on the board
/~RW: U8.3; also elsewhere on the board
GND: C7.2, C17.2, C19.2, C20.2, C21.2, U2.2 (K), U2.8 (GND), U8.7 (GND), U9.7 (GND), U10.7 (GND), U10.9, U10.10, U10.12, U10.13, U11.8 (GND); also elsewhere on the board
unnamed: R6.1, U2.3 (J)
unnamed: R7.1, U2.4 (~S)
unnamed: R8.1, U2.11 (J), U2.12 (K)
unnamed: R24.2, U2.9 (Q)
VCC: C7.1, C17.1, C19.1, C20.1, C21.1, R6.2, R7.2, R8.2, U2.16 (VCC), U8.14 (VCC), U9.14 (VCC), U10.14 (VCC), U11.16 (VCC); also elsewhere on the board

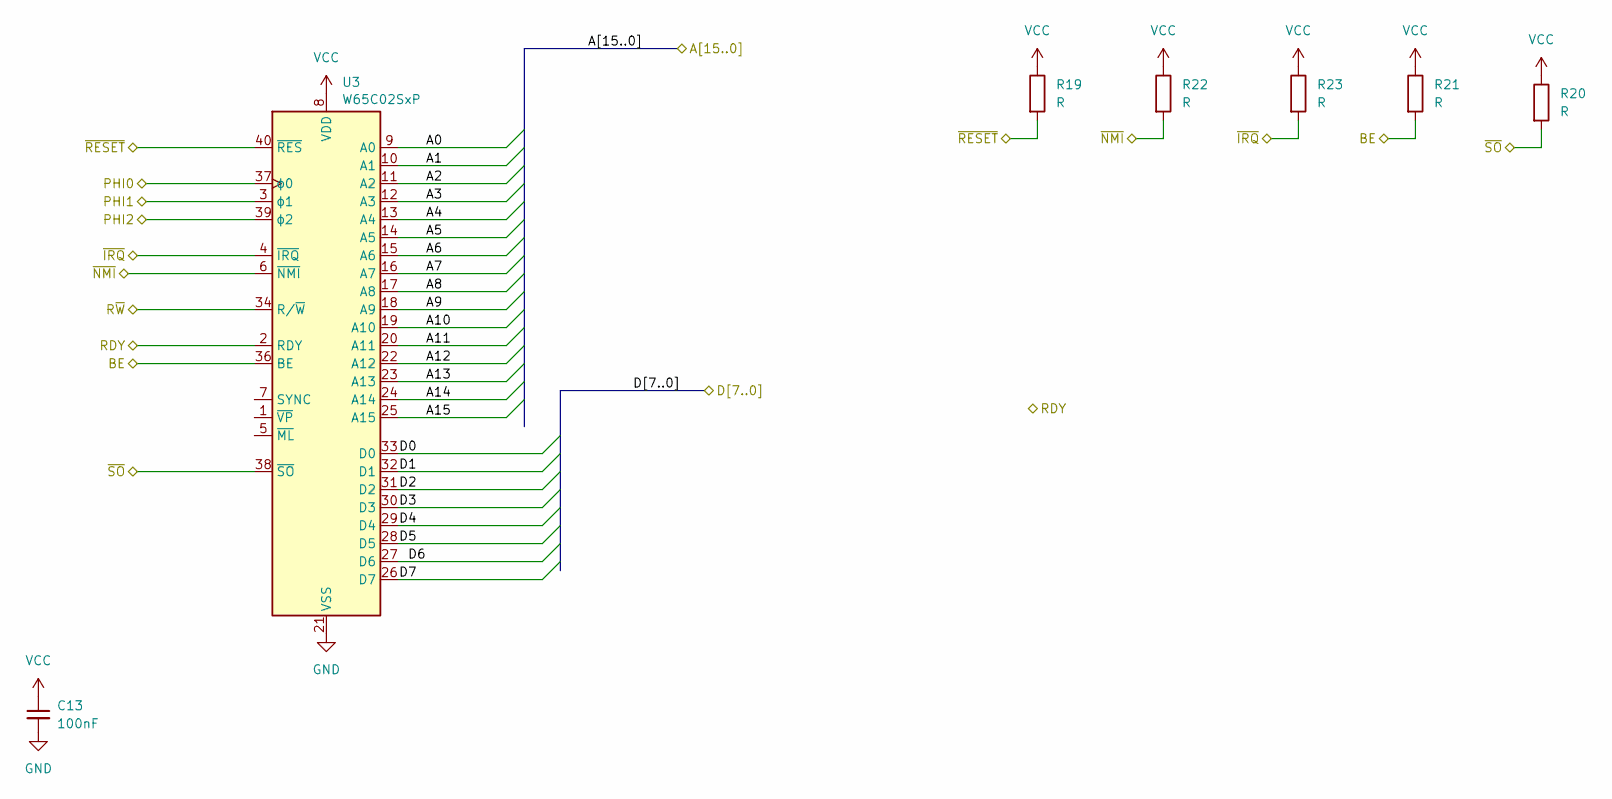
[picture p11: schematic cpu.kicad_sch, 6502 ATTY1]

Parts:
C13: 100nF; C_Disc_D4.3mm_W1.9mm_P5.00mm
R19, R20, R21, R22, R23: R; R_Axial_DIN0207_L6.3mm_D2.5mm_P10.16mm_Horizontal
U3: W65C02SxP; DIP-40_W15.24mm

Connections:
/A0: U3.9 (A0); also elsewhere on the board
/A1: U3.10 (A1); also elsewhere on the board
/A2: U3.11 (A2); also elsewhere on the board
/A3: U3.12 (A3); also elsewhere on the board
/A4: U3.13 (A4); also elsewhere on the board
/A5: U3.14 (A5); also elsewhere on the board
/A6: U3.15 (A6); also elsewhere on the board
/A7: U3.16 (A7); also elsewhere on the board
/A8: U3.17 (A8); also elsewhere on the board
/A9: U3.18 (A9); also elsewhere on the board
/A10: U3.19 (A10); also elsewhere on the board
/A11: U3.20 (A11); also elsewhere on the board
/A12: U3.22 (A12); also elsewhere on the board
/A13: U3.23 (A13); also elsewhere on the board
/A14: U3.24 (A14); also elsewhere on the board
/A15: U3.25 (A15); also elsewhere on the board
/CPU_CLK: U3.37 (ϕ0); also elsewhere on the board
/CPU_~IRQ: R23.2, U3.4 (~IRQ); also elsewhere on the board
/CPU_~NMI: R22.2, U3.6 (~NMI); also elsewhere on the board
/CPU_~RESET: R19.2, U3.40 (~RES); also elsewhere on the board
/D0: U3.33 (D0); also elsewhere on the board
/D1: U3.32 (D1); also elsewhere on the board
/D2: U3.31 (D2); also elsewhere on the board
/D3: U3.30 (D3); also elsewhere on the board
/D4: U3.29 (D4); also elsewhere on the board
/D5: U3.28 (D5); also elsewhere on the board
/D6: U3.27 (D6); also elsewhere on the board
/D7: U3.26 (D7); also elsewhere on the board
/PHI2O: U3.39 (ϕ2); also elsewhere on the board
/R~W: U3.34 (R/~W); also elsewhere on the board
/cpu/BE: R21.2, U3.36 (BE)
/cpu/PHI1: U3.3 (ϕ1)
/cpu/RDY: U3.2 (RDY)
/cpu/~SO: R20.2, U3.38 (~SO)
GND: C13.2, U3.21 (VSS); also elsewhere on the board
VCC: C13.1, R19.1, R20.1, R21.1, R22.1, R23.1, U3.8 (VDD); also elsewhere on the board

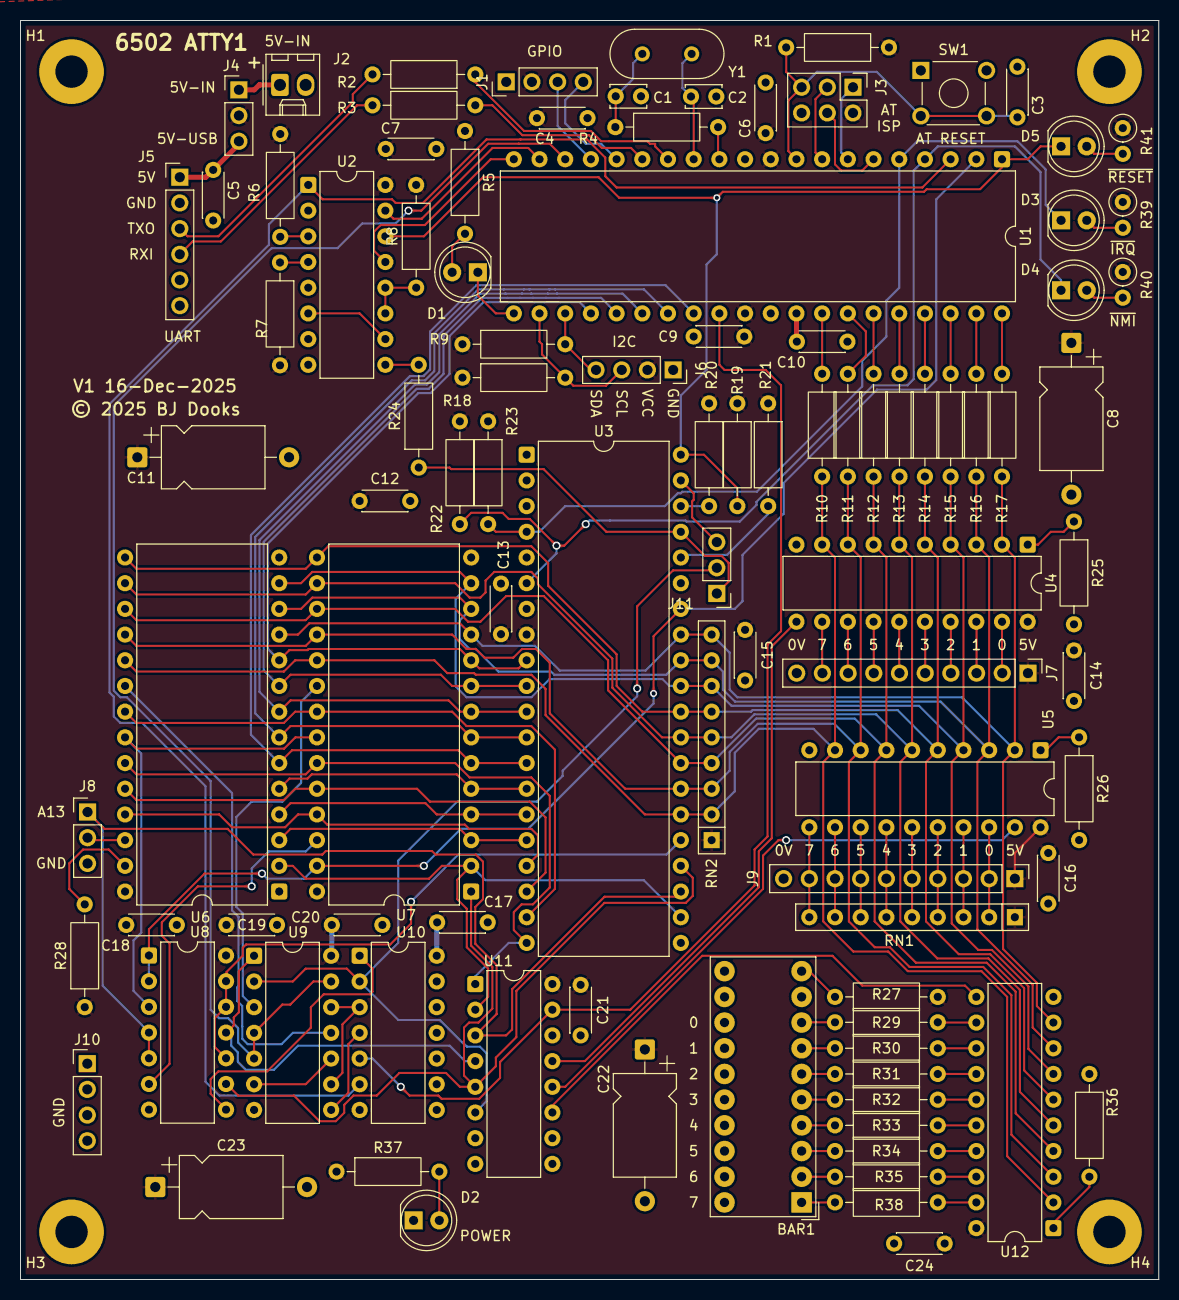
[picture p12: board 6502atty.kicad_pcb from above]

Board: 2 copper layers, 112.5 x 124.5 mm, 102 parts (0 on the bottom side), 127 nets.

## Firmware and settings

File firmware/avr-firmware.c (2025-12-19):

#include <avr/io.h>
#include <avr/power.h>
#include <avr/interrupt.h>
#include <avr/wdt.h>
#include <util/delay.h>
#include <util/twi.h>
#include <avr/pgmspace.h>

#include <stdio.h>
#include <string.h>
#include <stdarg.h>
#include <stdint.h>

void pf(const char *msg, ...);
  
#include "gpio.h"
#include "pins.h"
#include "pin_defaults.h"

#include "git-rev.h"
#include "build-info.h"

const char build_info[] = "BUILD: " BUILD_TYPE "\n" \
  "BUILD-BY: " BUILD_BY "\n" \
  "GIT-VER: " GIT_VERSION "\n" \
  "GIT-SHA: " GIT_HEAD "\n";

static void init_pwm(void)
{
	//TCCR2A = (2 << 4) /* OC2B = normal) */ | (2 << 0) /* CTC */;
	//TCCR2B = (1); /* no prescaler */

	TCCR2A = (2 << 4) | (1); /* for phase correct pwm */
	TCCR2B = (1) | (1 << 3);

	OCR2A = 0x10;
	OCR2B = 0x5;
}

static unsigned char ram[32] = {
#if 0
/*
* = $C000
C000 START  LDA #$00        A9 00
C002 LOOP   STA $C800       8D 00 C8
C005        ADC #$01        69 01
C007        SEC             38
C008        BCS LOOP        B0 F8
C00A .END
done.
*/
	0xa9, 0x00,
	0x8d, 0x00, 0x88 /* 0xc8 */,
	0x69, 0x01,
	0x38,
	0xb0, 0xf8,
	0x00, /* 0x0a */
	0x00, /* 0x0b */
	0x00, /* 0x0c */
	0x00, /* 0x0d */
	0x00, /* 0x0e */
	0x00, /* 0x0f */
#endif

#if 0
/*
*=$c000
LDX #$00
loop STX $801E
INX
JMP loop
.END
*/
	0xa2, 0x00,
	0x8e, 0x1e, 0x80,
	0xe8,
	0x4c, 0x02, 0xc0,
#endif


#if 0
	/*

*=$c000
LDX #$00
CLC
loop STX $801E
INX
BCC loop
.END
	*/

	0xa2, 0x00,
	0x18,
	0x8e, 0x1e, 0x80,
	0xe8,
	0x90, 0xfa,
#endif

#if 1
	/* note, the LDX should not affect C flag */
	/*
*=$c000
CLC
loop
LDX #0x00
STX $801E
BCC loop
JMP $800
.END
	 */

	0xa2, 0x00,
	0x8e, 0x1e, 0x80,
	0x90, 0xf9,
	0x4c, 0x00, 0x08,

#endif

};

ISR(TIMER1_COMPA_vect)
{
	//PORTD ^= 0x80;
	PORTB ^= 0x01;
}

/* set the clock divider post initialisation. The fuses only allow /1 or /8
 * and if we're using the 18.432 MHz option then the /2 option is probably
 * the best.
 */
static void init_clock(void)
{
	if (F_CPU == F_XTAL) {
		CLKPR = 0 | (1 << CLKPCE);
		CLKPR = 0;
	} else if (F_CPU == (F_XTAL / 2)) {
		CLKPR = 0 | (1 << CLKPCE);
		CLKPR = 1;
	} else {
		extern void __bad_crystal(void);
		__bad_crystal();	/* default to compiler link error */
	}

	/* wait for clock change to take place */
	while (CLKPR & (1 << CLKPCE)) { }
}

#define USART_BAUDRATE	115200
#define BAUD_PRESCALE	(((F_CPU / (USART_BAUDRATE * 16UL))) - 1)

 void init_uart(void)
{
	UBRR0L = BAUD_PRESCALE;
	UBRR0H = (BAUD_PRESCALE >> 8);

	UCSR0C = (1<<UCSZ00)|(1<<UCSZ01);		/* set to 8n1 */
	UCSR0B = (1 << TXEN0)| (1 << RXEN0);	/* enable rx/tx */
	//UCSR0B |= (1 << RXCIE) | (1 << TXCIE) | (1 << UDRIE);	/* irq enable */
}


/* uart handling routines */
static unsigned uart_hasbyte(void)
{
	return (UCSR0A & (1 << RXC0));
}

static uint8_t uart_getbyte(void)
{
	return UDR0;
}

static void uart_putbyte(uint8_t byte)
{
	while( (UCSR0A & (1<<UDRE0)) == 0) { }	/* wait for uart empty */
	UDR0 = byte;
}

static void uart_putc(uint8_t byte)
{
	if (byte == '\n')
		uart_putbyte('\r');
	uart_putbyte(byte);
}

/* simple printf-like routine with small buffer */
void pf(const char *msg, ...)
{
	va_list va;
	char buff[40];
	int off, len;

	va_start(va, msg);
	len = vsnprintf(buff, sizeof(buff), msg, va);
	va_end(va);

	for (off = 0; off < len; off++)
		uart_putc(buff[off]);
}

/* hand assembled 6502 for doing stuff */

const unsigned char download_code[] PROGMEM = {
	/*

*=$c000
LDX #$00
loop STX $801E
INX
BCC loop
BRK
.END
	*/
	0xa2, 0x00,
	0x18,
	0x8e, 0x1e, 0x80,
	0xe8,
	0x90, 0xfa,
	0x00,
};


static const unsigned char ramtest_code_read[] PROGMEM = {
/*
*=$c000
//CLC
loop
LDX $0123
STX $801F
BCC loop
.END
*/
	//0x18,
	0xae, 0x23, 0x01,
	0x8e, 0x1f, 0x80,
	0x90, 0xf8,
};

const unsigned char *download_ptr = download_code;
unsigned download_to = 0x800;
unsigned download = sizeof(download_code);

static const unsigned ram_sz = 8 * 1024;
static unsigned ram_test_ptr = 0x0000;
static unsigned ram_test = 1;

static unsigned ram_test_pattern(unsigned addr)
{
	// really simple ram test pattern
	return (addr ^ (addr >> 8));
}

static void halt(void)
{
	PORTB &= ~(1 << 0);
	PORTD &= ~(1 << 7);		

}

static void ram_test_isr_code(unsigned addr)
{
	unsigned int ptr;

	/* assume addr has been checked and is 1 */

	if (ram_test_ptr >= ram_sz) {
		ram_test++;
		ram_test_ptr = 0x0;

		switch (ram_test) {
		case 2:
			pf("RAM test - patterns written\n");

			for (ptr = 0x00; ptr < 0x10; ptr++)
				ram[ptr] = pgm_read_byte(ramtest_code_read + ptr);

			PORTA = ram[1];
			break;
		case 3:
			pf("RAM test done\n");
			halt();
			/* done */
		}
	} else if (ram_test_ptr == 0x00) {
		pf("RAM test - pass %d\n", ram_test);
	} else if ((ram_test_ptr & 0xff) == 0) {
		pf(".");
	}
	
	switch (ram_test) {
	case 1:
		ram[1] = ram_test_pattern(ram_test_ptr);
		ram[3] = ram_test_ptr & 0xff;
		ram[4] = ram_test_ptr >> 8;
		ram_test_ptr++;
		break;
	case 2:
		ram[1] = ram_test_ptr & 0xff;
		ram[2] = ram_test_ptr >> 8;
		break;
	}

}

static unsigned dump_mem;
static unsigned count = 0;

// seem to be seeing double execution of the CLC instruction at 0x00
// but with two cycles, the first is addr, adn then with addr+1

/* update the download code ram when addr+0x0 is read so that the
 * download data is there and if the download is finished we continue
 * on past the BCC loop
 */
static inline void update_download_state(void)
{
	ram[1] = pgm_read_byte(download_ptr);
	ram[3] = download_to & 0xff;
	ram[4] = download_to >> 8;
	pf("DL %04x %02x (C=%d)\n", download_to, ram[2], count);

	download_to++;
	download_ptr++;
	download--;

	if (download == 0) {
		pf("Download done\n");
		ram[5] = 0xb0;  /* change BCC to BCS */
	} else {
		ram[5] = 0x90;
	}
}

/* device is reading from emulated rom, so we need to return a value on the
 * data lines depending on the address
 */
static inline void handle_rom_read(unsigned addr)
{
	PORTA = ram[addr];

	if (addr == 0x1e) {
		unsigned ptr;
		pf("BRK!\n");

		for (ptr = 0x00; ptr < 0x10; ptr++)
			ram[ptr] = pgm_read_byte(ramtest_code_read + ptr);

		PORTA = ram[addr];
		download_to = 0x1fc;
		dump_mem  = 1;
		download = 0;
		ram_test = 0;
		ram[5] = 0x1d;  // change where memory is written to
	}

	if (download) {
		if (addr == 0)
			update_download_state();
	} else if (ram_test) {
		if (addr == 0)
			ram_test_isr_code(addr);

	} else if (dump_mem) {
		if (addr == 0) {
			pf("DBG %04x = ", download_to);
			ram[1] = download_to & 0xff;
			ram[2] = download_to >> 8;
			download_to++;
			if (download_to == 0x200)
				download_to = 0x800;
			if (download_to > 0x810) {
				halt();
			}
		}

	}
}

static void handle_dev_write(unsigned addr, unsigned data)
{
	unsigned tmp;
	
	switch (addr) {
	case 0x1d:
		pf("%02x\n", data);
		break;
	case 0x1e:
		pf("DBG %02x\n", data);
		break;

	case 0x1f:
		tmp =  ram_test_pattern(ram_test_ptr) & 0xff;
		if (data == tmp) {
			// good, ignore //
		} else {
			pf("RT %04x -> got %02x want %02x, diff %02x\n",
			   ram_test_ptr, data, tmp, data ^ tmp);
			_delay_ms(100);
		}
		ram_test_ptr++;
		break;

	default:
		if (1)
			pf("DW unhandled %02x %02x\n", addr, data);
	}
}

ISR(INT2_vect)
{
	unsigned portc = PINC;
	unsigned addr = portc >> 2;
	unsigned read = PINB & (1 << 1);

	addr &= 0x1f;

	if (read) {
		if ((portc & (1 << 7)) == 0) {
			pf("RD %02x = %02x C=%u\n", addr, ram[addr], count);
		} else {
			if (0 || (addr >= 0x1e) || dump_mem)
				pf("RD %02x = %02x C=%u\n", addr, ram[addr], count);

			handle_rom_read(addr);
		}
	} else {
		unsigned data;

		/* handle write to device */

		DDRA = 0x00;
		_delay_us(1);
		data = PINA;
		DDRA = 0xff;

		if (0)
			pf("WR %02x %02x\n", addr, data);

		if ((portc & (1 << 7)) == 0) {
			handle_dev_write(addr, data);
		} else {
			pf("WR %02x %02x\n", addr, data);

		}
	}

	/* pulse ack pin to let the 6502 continue */
	set_pin(PIN_AT_ACK, 0);
	set_pin(PIN_AT_ACK, 1);

	count++;
}

int main(void)
{

	cli();
	wdt_disable();

	count = 0;

	if (1) {
	  pf("6502Atty (" GIT_VERSION ")\n");
	}

	/* initialise our virtual ram/rom */
	ram[0xFC & 0x1f] = 0x00;
	ram[0xFD & 0x1f] = 0xC0;  // set "rom" as reset vectir
	ram[0xFE & 0x1f] = 0x00;
	ram[0xFF & 0x1f] = 0xC0;  // set "rom" as break vectir

	init_gpio();
	init_clock();
	init_pwm();
	init_uart();

	sei();

	/* prototype needs to release master reset */
	_delay_ms(100);
#ifdef PIN_MAIN_RESET
	set_pin(PIN_MAIN_RESET, 1);
#endif

	/* enable interrupts */

	EICRA = (1 << ISC21) | (0 << ISC20);
	EIMSK = (1 << 2);

#if 0
	/* timer to toggle leds for testing */

	TCCR1B |= (1 << WGM12); // Configure timer 1 for CTC mode
        OCR1A = 39062/20;        // Set CTC compare value to 1Hz at 8MHz F_CPU (prescale 256)
        TCCR1B |= (1 << CS12);  // Start timer at Fcpu/256

        TIMSK1 = (1 << OCIE1A);
#endif	

	pf("\nstarting 6502..\n");

	_delay_ms(100);
	set_pin(PIN_6502_nRESET, 1);	/* release 6502 reset */

	while (1) { }
}

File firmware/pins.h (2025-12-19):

/* pin definitons for ATMega
 *
 * Copyright 2025 Ben Dooks <6502atty@ben.fluff.org>
*/

#define BANK_A  (0)
#define BANK_B  (8)
#define BANK_C  (16)
#define BANK_D  (24)

/* PIN(bank, number, defaults)
 *
 * DEF_INPUT - input with no pull-up
 * DEF_INPUT_PU - input with pull-up
 * DEF_OUTPUT_0 - pin is output, value 0
 * DEF_OUTPUT_1 - pin is output, value 1
*/

#if 0
/* default to input, pull-up */
#define PIN_DB0		PIN(BANK_A, 0, DEF_INPUT_PU)
#define PIN_DB1		PIN(BANK_A, 1, DEF_INPUT_PU)
#define PIN_DB2		PIN(BANK_A, 2, DEF_INPUT_PU)
#define PIN_DB3		PIN(BANK_A, 3, DEF_INPUT_PU)
#define PIN_DB4		PIN(BANK_A, 4, DEF_INPUT_PU)
#define PIN_DB5		PIN(BANK_A, 5, DEF_INPUT_PU)
#define PIN_DB6		PIN(BANK_A, 6, DEF_INPUT_PU)
#define PIN_DB7		PIN(BANK_A, 7, DEF_INPUT_PU)
#endif


#if 1
/* default to output, value should be 0xEA */
#define PIN_DB0		PIN(BANK_A, 0, DEF_OUTPUT_0)
#define PIN_DB1		PIN(BANK_A, 1, DEF_OUTPUT_1)
#define PIN_DB2		PIN(BANK_A, 2, DEF_OUTPUT_0)
#define PIN_DB3		PIN(BANK_A, 3, DEF_OUTPUT_1)
#define PIN_DB4		PIN(BANK_A, 4, DEF_OUTPUT_0)
#define PIN_DB5		PIN(BANK_A, 5, DEF_OUTPUT_1)
#define PIN_DB6		PIN(BANK_A, 6, DEF_OUTPUT_1)
#define PIN_DB7		PIN(BANK_A, 7, DEF_OUTPUT_1)
#endif

#define PIN_6502_nRESET PIN(BANK_B, 1, DEF_OUTPUT_0)
#define PIN_ROM_SEL	PIN(BANK_D, 4, DEF_OUTPUT_1)	/* start with ATMega as 'ROM' */
#define PIN_AT_ACK	PIN(BANK_D, 5, DEF_OUTPUT_1)

#define PIN_SER_TX0	PIN(BANK_D, 1, DEF_OUTPUT_1)	/* output 1 for serial transmit */
#define PIN_PWN_CLK	PIN(BANK_D, 6, DEF_OUTPUT_1)	/* output 1 to use pin as PWM */


/* prototype defines */

#ifdef BUILD_PROTOTYPE
#define PIN_MAIN_RESET	PIN(BANK_D, 7, DEF_OUTPUT_0)
#endif

/* release1 defines */

#ifdef BUILD_RELEASE

#define PIN_AT_LED	PIN(BANK_D, 7, DEF_OUTPUT_1)
#endif

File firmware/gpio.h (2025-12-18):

#define PIN(__bank, __pin, __default) ((__bank) + (__pin))

static inline int read_gpio(int pin)
{
	int offs = pin & 7;
	switch (pin >> 3) {
	case 0:	return PINA & (1 << offs);
	case 1:	return PINB & (1 << offs);
	case 2:	return PINC & (1 << offs);
	case 3:	return PIND & (1 << offs);
	default:
		return 0;
	}

	return 0;
}

static inline int get_ddr(int pin)
{
	int offs = pin & 7;
	switch (pin >> 3) {
	case 0:	return DDRA & (1 << offs);
	case 1:	return DDRB & (1 << offs);
	case 2:	return DDRC & (1 << offs);
	case 3:	return DDRD & (1 << offs);
	default:
		return 0;
	}

	return 0;
}

#define get_pin(__p) read_gpio(__p)

static inline void set_pin(int pin, int to)
{
	int offs = pin & 7;

	if (1) {
		if (get_ddr(pin) == 0)
			pf("DDR not set (%d)\n", pin);
	}

	if (to) {
		switch (pin >> 3) {
		case 0: PORTA |= (1 << offs); break;
		case 1: PORTB |= (1 << offs); break;
		case 2: PORTC |= (1 << offs); break;
		case 3: PORTD |= (1 << offs); break;
		default: pf("Unknown pin %d\n", pin);
		}
	} else {
		switch (pin >> 3) {
		case 0: PORTA &= ~(1 << offs); break;
		case 1: PORTB &= ~(1 << offs); break;
		case 2: PORTC &= ~(1 << offs); break;
		case 3: PORTD &= ~(1 << offs); break;
		default: pf("Unknown pin %d\n", pin);
		}
	}
}

static inline void set_ddr(int pin, int to)
{
	int offs = pin & 7;

	if (to) {
		switch (pin >> 3) {
		case 0: DDRA |= (1 << offs); break;
		case 1: DDRB |= (1 << offs); break;
		case 2: DDRC |= (1 << offs); break;
		case 3: DDRD |= (1 << offs); break;
		}
	} else {
		switch (pin >> 3) {
		case 0: DDRA &= ~(1 << offs); break;
		case 1: DDRB &= ~(1 << offs); break;
		case 2: DDRC &= ~(1 << offs); break;
		case 3: DDRD &= ~(1 << offs); break;
		}
	}
}
static inline void toggle_pin(int pin)
{
	int offs = pin & 7;

	switch (pin >> 3) {
	case 0: PORTA ^= (1 << offs); break;
	case 1: PORTB ^= (1 << offs); break;
	case 2: PORTC ^= (1 << offs); break;
	case 3: PORTD ^= (1 << offs); break;
	}
}

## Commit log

2025-12-18 Initial project release
    - add kicad project from current first release
    - add firmware from original board (not yet modified for new version)
    - put license file in, as a fairly permissive
    Any questions, email is 6502atty@ben.fluff.org
    [6502atty.kicad_pcb, 6502atty.kicad_sch, atmega.kicad_sch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]
2025-12-18 fix use of __bad_crystal being undefined
    [avr-firmware.c]
2025-12-18 fix return type of main() to be int
    [avr-firmware.c]
2025-12-18 move to using pin code for workong on release
2025-12-18 code fix for added bracker
    [avr-firmware.c]
2025-12-19 add git-rev.h and print basic version info
2025-12-19 add hex values ot pin defaults
2025-12-19 update kicad .gitignore (help from https://github.com/github/gitignore/commit/b93d2b024a21982b2e593735ceaf794b21334d04)

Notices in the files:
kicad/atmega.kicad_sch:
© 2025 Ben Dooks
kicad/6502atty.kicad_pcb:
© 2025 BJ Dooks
